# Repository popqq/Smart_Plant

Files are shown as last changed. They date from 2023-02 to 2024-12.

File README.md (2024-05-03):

[][documentation]
[](LICENSE)
[][maintenance]
[][buyit]

# Smart Plant
The Smart Plant is a board that can be plugged directly on the soil, close to the plant, that allows the measurement of the environment (soil moisture, environment temperature & illuminance), and presents the information on an ePaper display.

<p float="left">
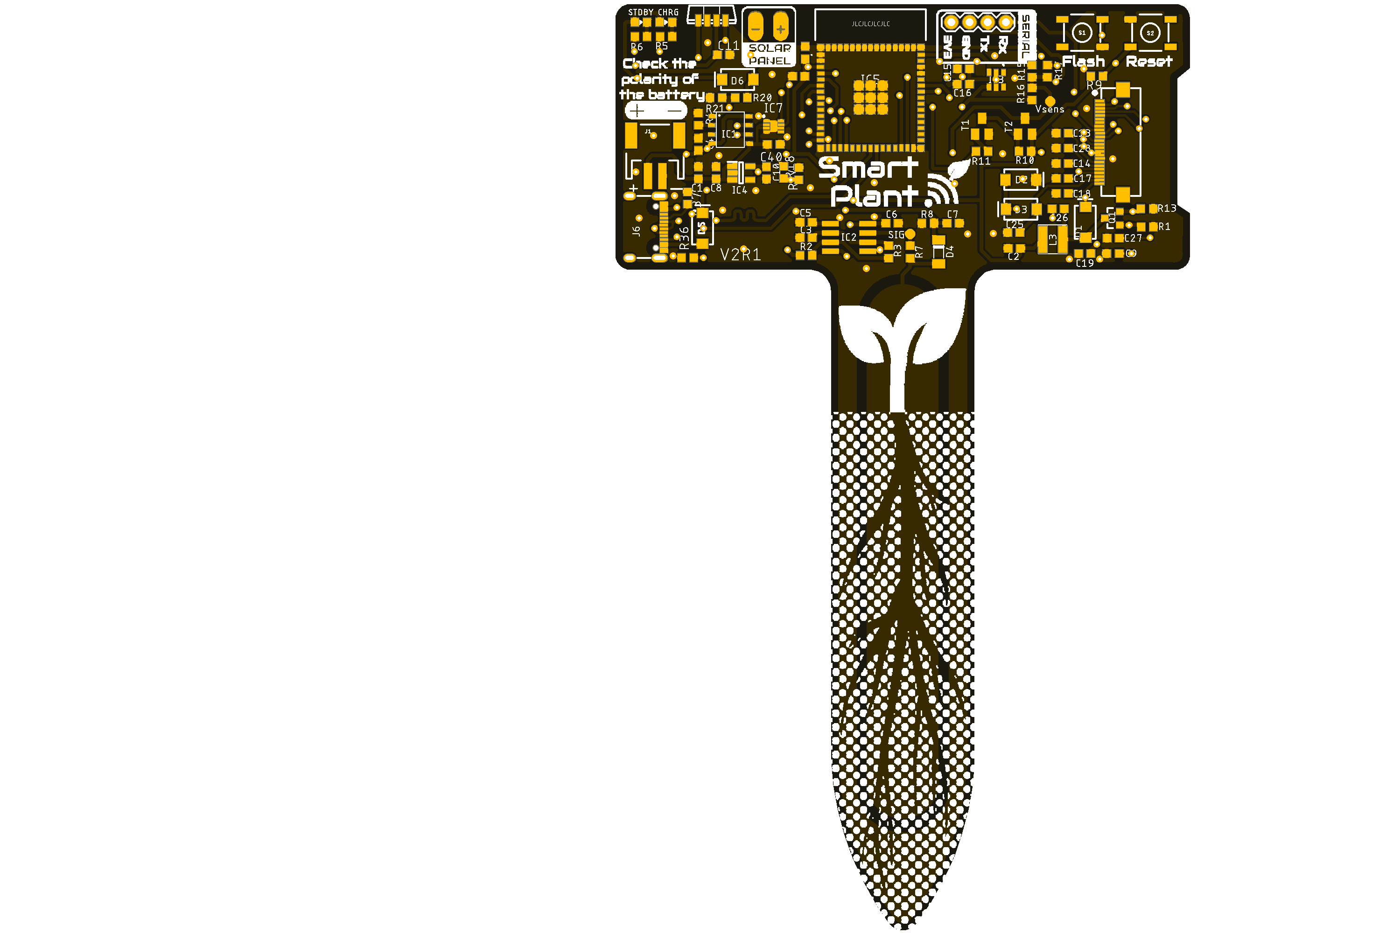
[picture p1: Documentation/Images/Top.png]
   
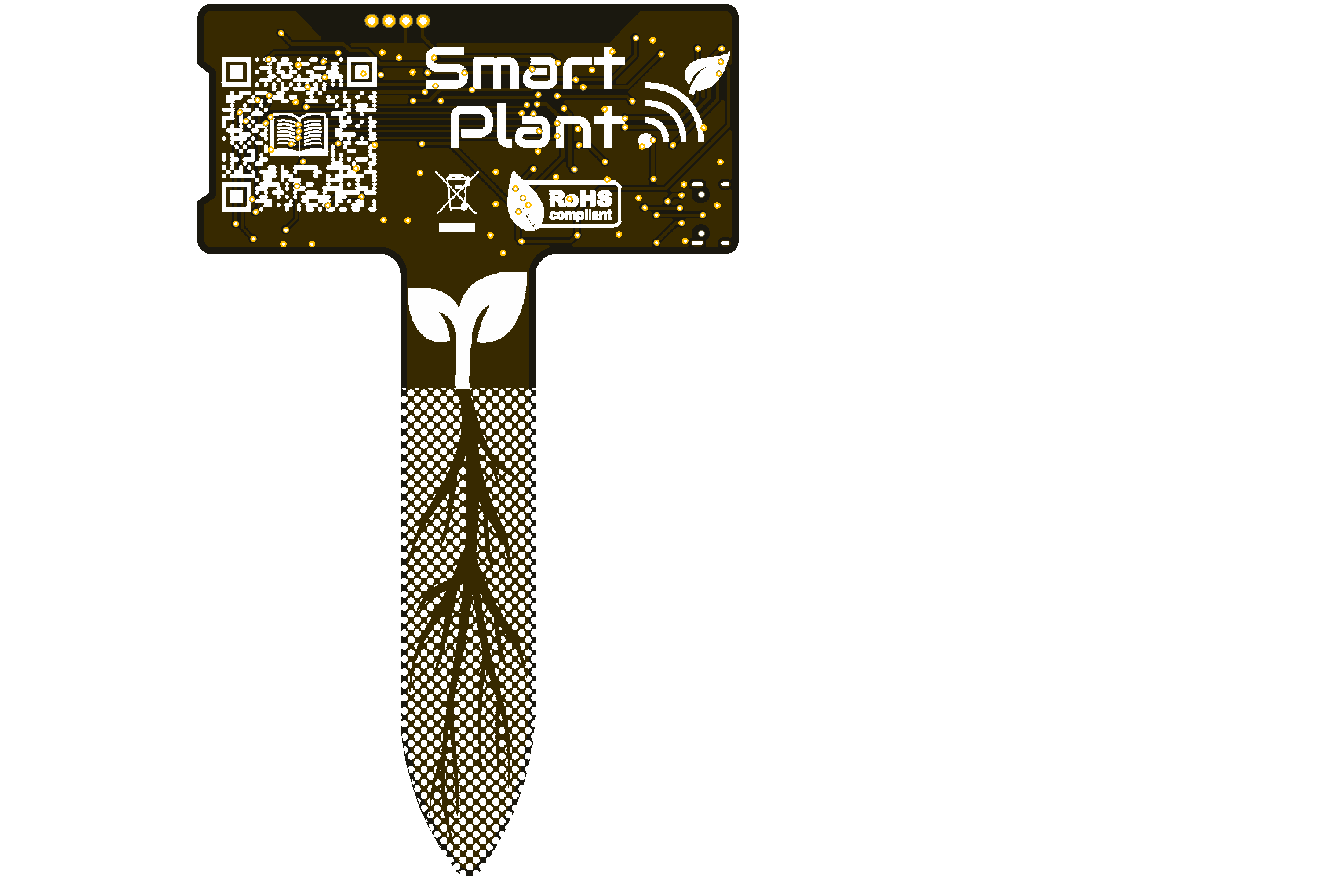
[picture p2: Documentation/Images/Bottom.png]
      
</p>

## Project tree

<li><a href="./Design/">Design</a></li>
<li><a href="./Documentation/">Documentation</a></li>

<li><a href="./README.md">README.md</a></li>

[documentation-shield]: https://readthedocs.org/projects/smart-plant/badge/?version=v2r1&style=for-the-badge
[documentation]: https://smart-plant.readthedocs.io/

[license-shield]: https://img.shields.io/badge/License-CC%20BY--NC--SA%204.0-lightgrey.svg?style=for-the-badge

[maintenance-shield]: https://img.shields.io/badge/maintainer-J.%20G.%20Aguado-2e48a7.svg?style=for-the-badge
[maintenance]: https://github.com/JGAguado

[buyit-shield]: https://img.shields.io/badge/get%20it%20on-elecrow-399BD7.svg?style=for-the-badge
[buyit]: https://www.elecrow.com/smart-plant.html

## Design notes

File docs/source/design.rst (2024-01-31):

📐 Design
===========================

Electronic schematics
---------------------
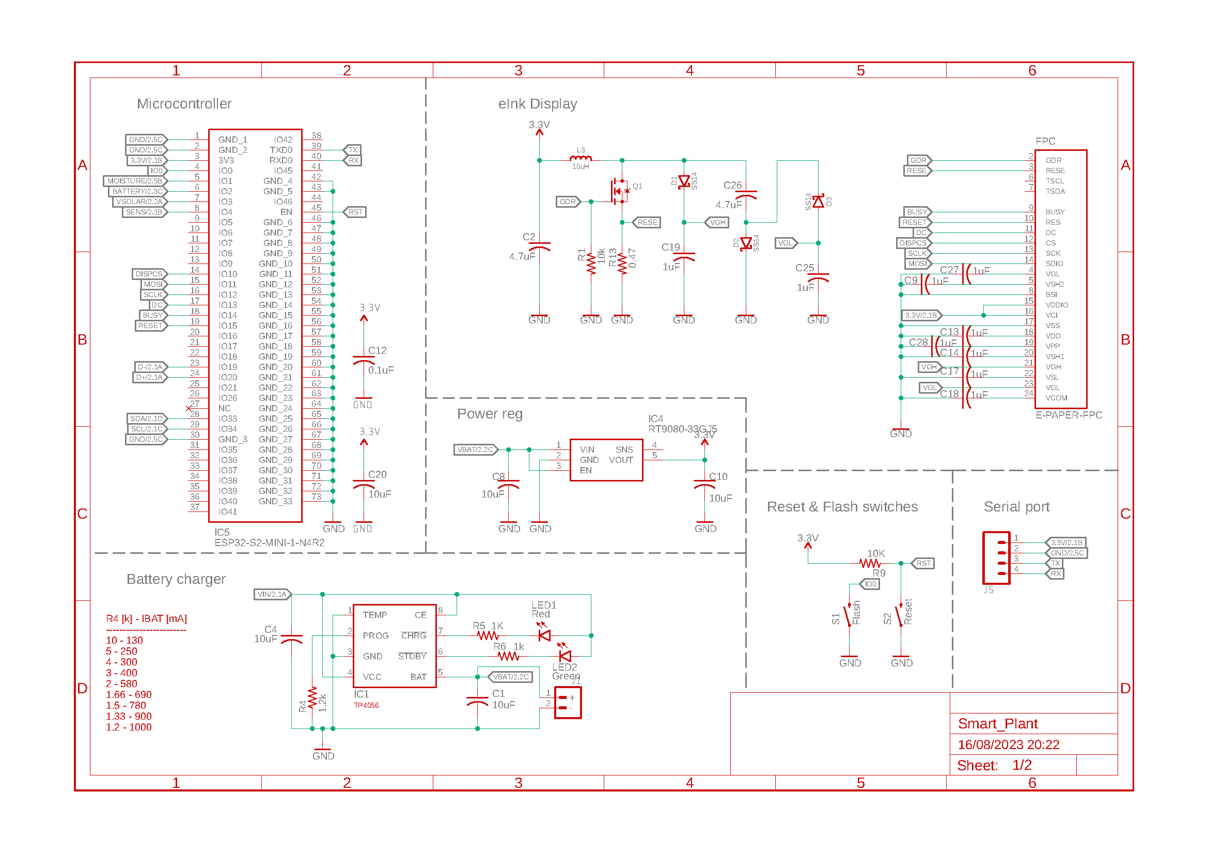
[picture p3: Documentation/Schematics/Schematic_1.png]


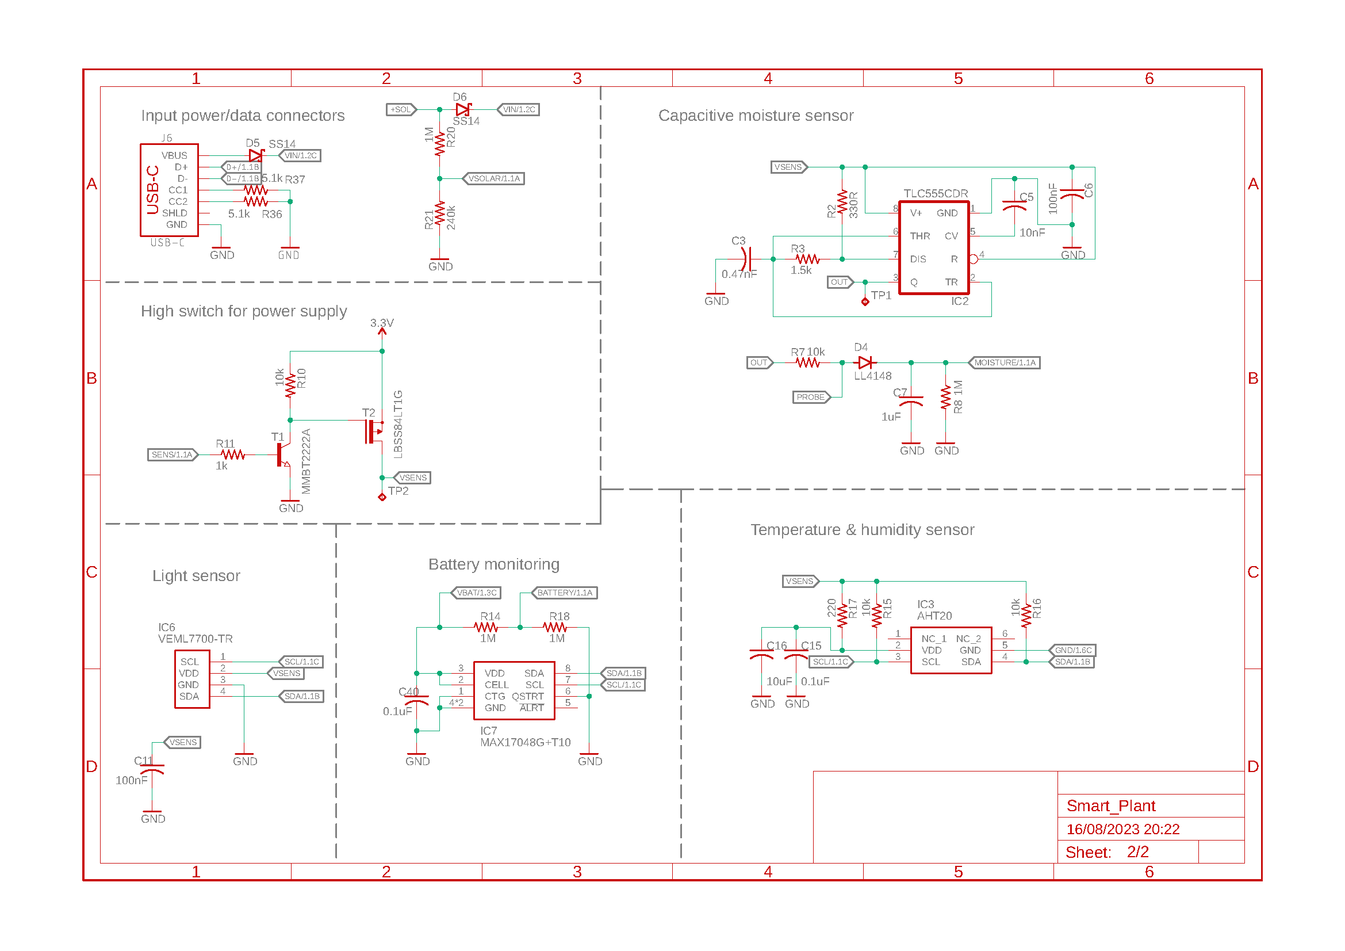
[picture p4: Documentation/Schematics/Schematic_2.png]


:download:`Download PDF <../../Documentation/Schematics/Schematic.pdf>`

.. _pcb:

:term:`PCB`
----------

.. raw:: html

    <iframe src="_static/ibom.html" height="800px" width="100%"></iframe>

.. _enclosure:

3D printable enclosure
-----------------------

FDM version
^^^^^^^^^^^^^^^^^
This 3D model is intended to be printed on :term:`FDM` printers. Check your printing configuration for obtaining the best results on ~2mm thick walls.

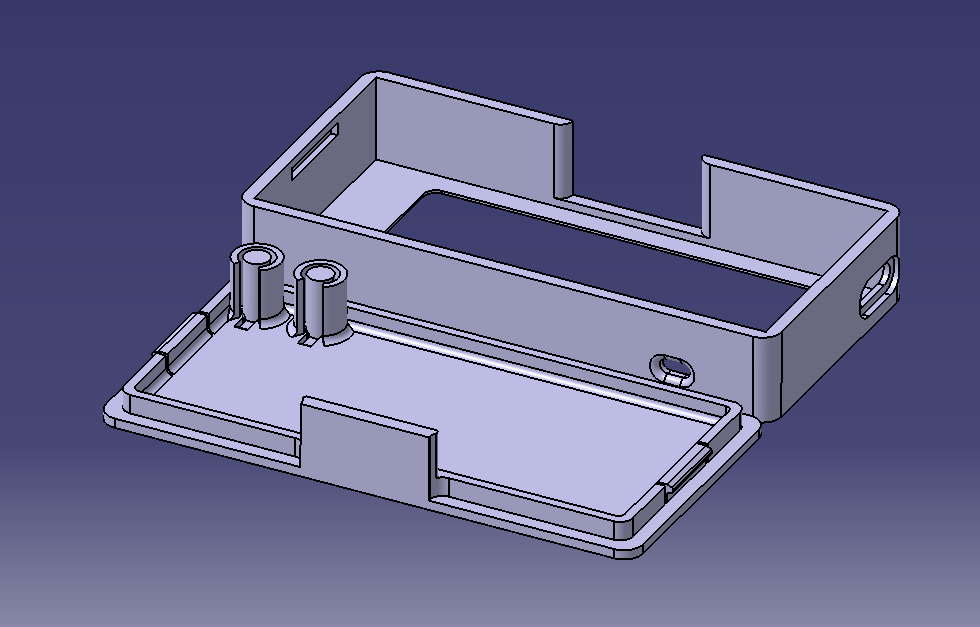
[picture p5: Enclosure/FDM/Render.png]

    
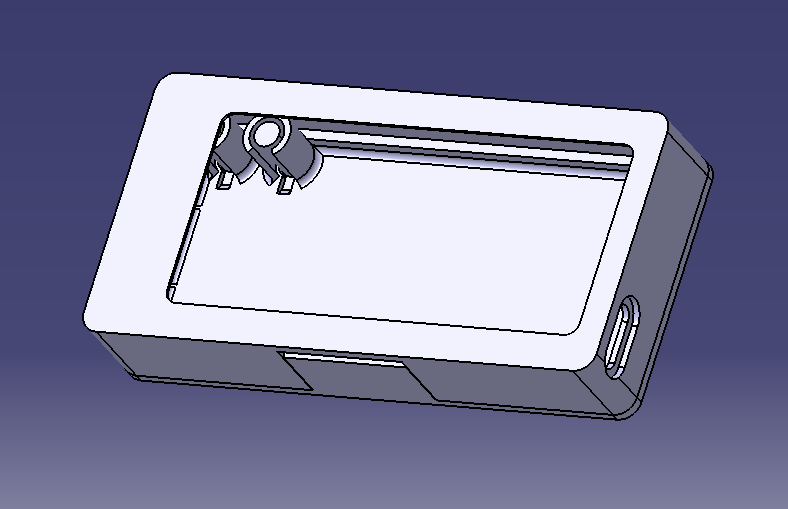
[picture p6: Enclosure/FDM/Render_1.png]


|

Printable STL files:

- :download:`Bottom STL<../../Enclosure/FDM/Smart-Plant Enclosure Bottom.stl>`
- :download:`Top STL<../../Enclosure/FDM/Smart-Plant Enclosure Top.stl>`

Editable STEP files:

- :download:`Bottom STP<../../Enclosure/FDM/Smart-Plant Enclosure Bottom.stp>`
- :download:`Top STP<../../Enclosure/FDM/Smart-Plant Enclosure Top.stp>`

SLA version
^^^^^^^^^^^^^^^^^
This 3D model is intended to be printed on :term:`SLA` printers. 
If you want to use transparent resins, you can download the *Top transparent* version, without holes for the sensor or the display.


    


|

Printable STL files:

- :download:`Bottom STL<../../Enclosure/SLA/Smart-Plant Enclosure Bottom.stl>`
- :download:`Top STL<../../Enclosure/SLA/Smart-Plant Enclosure Top.stl>`
- :download:`Top transparent STL<../../Enclosure/SLA/Smart-Plant Enclosure Top - Transparent.stl>`

Editable STEP files:

- :download:`Bottom STP<../../Enclosure/SLA/Smart-Plant Enclosure Bottom.stp>`
- :download:`Top STP<../../Enclosure/SLA/Smart-Plant Enclosure Top.stp>`
- :download:`Top transparent STP<../../Enclosure/SLA/Smart-Plant Enclosure Top - Transparent.stp>`

Community's versions
^^^^^^^^^^^^^^^^^^^^^^

- `@Paulomart <https://github.com/Paulomart>`_ created a more streamlined button operation version for the bottom part. Check it out on `Printables <https://www.printables.com/de/model/745390-smart-plant-bottom-enclosure-with-improved-buttons>`_.



Technical Specifications
-------------------------

Microcontroller 
^^^^^^^^^^^^
.. list-table:: 
    :widths: 50 80
    :stub-columns: 1

    * - Module
      - ESP32-S2-MINI-1
    * - SoC
      - Xtensa® singlecore 32-bit LX7 up to 240MHz
    * - Flash
      - 4MB
    * - PSRAM
      - 2MB

Power
^^^^^^^^^^^^

.. list-table:: 
    :widths: 50 80
    :stub-columns: 1

    * - Battery 
      - LiPo 3.7 V 1000 mAh
    * - Input (USB/Solar panel)
      - 5V @ 500mA

Features
^^^^^^^^^^^^

.. list-table:: 
    :widths: 50 80
    :stub-columns: 1

    * - Interface 
      - USB Type C 
    * - 
      - 2.4GHz WiFi 
    * - 
      - UART
    * - Display
      - 2.9" e-paper 
    * - Sensors
      - Capacitive soil moisture probe (analog)
    * - 
      - VEML7700-TR illuminance sensor (digital :math:`I^2C`)
    * - 
      - AHT20 air temperature & relative humidity sensor (digital :math:`I^2C`)
    * - 
      - MAX17048 battery voltage level sensor (digital :math:`I^2C`)

Dimensions
^^^^^^^^^^^^

.. list-table:: 
    :widths: 50 80
    :stub-columns: 1

    * - Size 
      - 130x80x7mm
    * - 
      - 132x84x15mm with enclosure
    * - Weight
      - 20g
    * - 
      - 45g with battery

Environment
^^^^^^^^^^^^
.. Caution::
    If the |Product| is placed on the soil close to the plant, be careful at the moment of wattering your plant: avoid splashes 
    or flooding the pot.

.. list-table:: 
    :widths: 50 20 20 20 20 20
    :header-rows: 1
    :stub-columns: 1

    * - Parameter
      - Symbol
      - Min.
      - Typ.
      - Max.
      - Unit
    * - Working temperature [1]_
      - :math:`T_{amb}`
      - 0
      - 25 
      - 60
      - *°C*
    * - Storage temperature [1]_
      - :math:`T_{amb}`
      - 0
      - 25 
      - 60
      - *°C*

.. [1] Based on components datasheets.

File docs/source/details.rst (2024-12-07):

💡 Details
===============

.. _pinout:

Pinout
---------
The |Product| integrates an ESP32-S2 microcontroller with the following pinout:

.. list-table:: Pinout table
    :widths: 10 10 40
    :header-rows: 1

    * - **Component**
      - **Pin**
      - **Description**
    * - **I²C**
      - 
      - 
    * - Serial Clock Line (SCL)
      - GPIO34
      - Used for I²C communication clock signal
    * - Serial Data Line (SDA)
      - GPIO33
      - Used for I²C communication data signal
    * - **SPI**
      - 
      - 
    * - Clock (CLK)
      - GPIO12
      - SPI clock signal
    * - Master Out Slave In (MOSI)
      - GPIO11
      - SPI data from master to slave
    * - **Analog/Digital Sensors**
      - 
      - 
    * - Battery Voltage (ADC)
      - GPIO2
      - Reads battery voltage level
    * - Solar Input (ADC)
      - GPIO3
      - Reads voltage from the solar input pad
    * - Soil Moisture (ADC)
      - GPIO1
      - Measures soil moisture
    * - **Digital Outputs**
      - 
      - 
    * - Excitation Switch
      - GPIO4
      - Controls excitation signal for powering the sensors
    * - **Display (WaveShare E-Paper)**
      - 
      - 
    * - Chip Select (CS)
      - GPIO10
      - Selects the e-paper display module
    * - Data/Command (DC)
      - GPIO13
      - Differentiates between data and commands
    * - Busy Indicator (BUSY)
      - GPIO14
      - Signals when the display is busy
    * - Reset (RST)
      - GPIO15
      - Resets the display module

Power
--------
The |Product| is be powered through a :term:`LiPo` battery plugged into the white JST connector. The voltage of the battery is regulated to the working 3.3V through a low-consumption :term:`LDO`.

.. Caution::
    Connect the battery after clamping the e-paper connector and be careful when plugging it or removing it, since the connector can be hard to plug/unplug.

In order to charge the battery, there is a battery management IC that provides the right charging curve to the :term:`LiPo` battery and offers a visual indicator (red LED for charging, 
green LED for standby) while the battery is being charged. There are two ways of charging the |Product|: USB-C or solar panel.

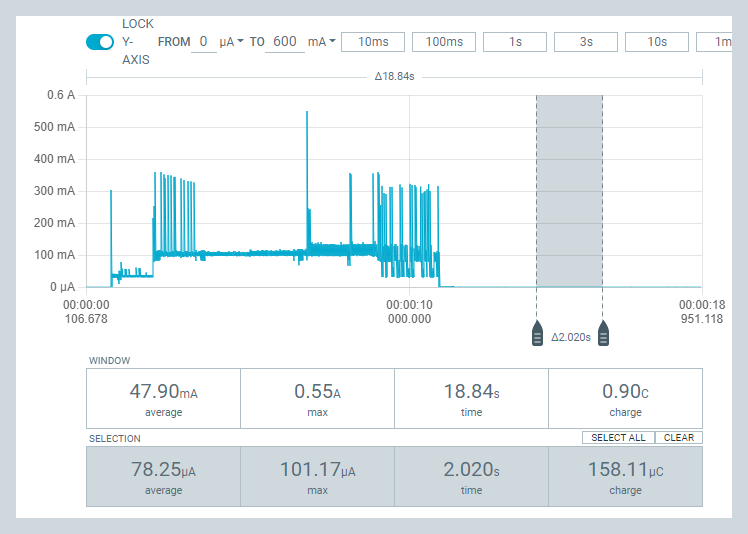
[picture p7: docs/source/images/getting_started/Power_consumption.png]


Solar panel
^^^^^^^^^^^^^
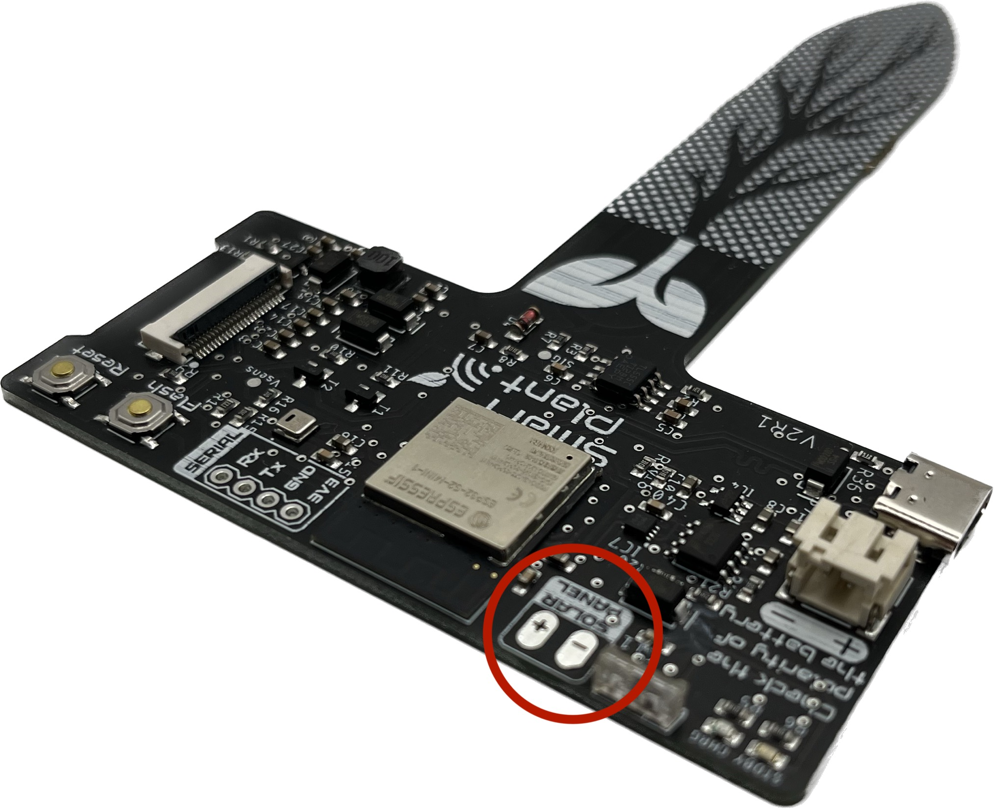
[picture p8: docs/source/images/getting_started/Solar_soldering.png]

    
In addition to the USB-C, and with the aim of extending the service time between (USB) charges of the battery, the |Product| can be configured to be powered from a solar panel. This feature 
would imply soldering the solar pannel to the board as indicated in the figure.

USB-C
^^^^^^^^^^^^^
The USB Type-C is a very extended port for portable electronics, and because of it's standarized 5V power supply is ideal for charging the |Product|.

Sensors
--------   
As the |Product| is intended to work during long periods of time without having to be recharged, it is important to avoid undesired consumptions 
durint the deep-sleep periods. This implies that the sensors have to be powered **only** when they are needed. 

Therefore there is a high-switch circuit that enables/disables the powering of the *sensors power line* connected to the microcontroller's output **GPIO4**.

Regarding the sensors, and except for the soil moisture sensor which is analog, the rest (illuminance, temperature & humidity, battery status) are :term:`IIC` (:math:`I^2C`) sensors,
which are physically defined with the following pinout:

:SDA: **GPIO33**
:SCL: **GPIO34**

Soil moisture
^^^^^^^^^^^^^^
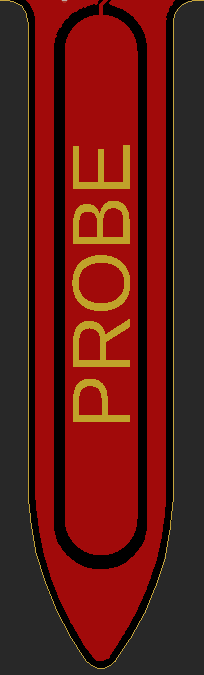
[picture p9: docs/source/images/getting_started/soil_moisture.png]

    
Since the |Product| can be directly inserted into the soil of your pot, the area inserted contains a printed circuit that behaves as a 
probe that measures the soil capacity, determined by the soil moisture. As it has no metallic electrodes, there is no risk of probe degradation 
with time. 

The moisture level, in a 0-3.3V range, is measured through the ADC on **GPIO1**

|
|

Light sensor
^^^^^^^^^^^^^^^^^^^^^^^
The illuminance is measured through a digital sensor VEML7700-TR. This sensor is located facing the outside of the top part of the board, so it 
would be facing the sky. 

The VEML7700 is quite a convenient sensor since it delivers the values directly in lux. 
The sensor has 16-bit dynamic range for ambient light detection from 0 lux to about 120k lux with resolution down to 0.0036 lx/ct, 
with software-adjustable gain and integration times.

The :math:`I^2C` address is **0x10**.

.. Hint::
    If you are designing your own enclosure, make sure there is a hole for the light sensor on the case.

Ambient temperature & humidity 
^^^^^^^^^^^^^^^^^^^^^^^^^^^^^^^
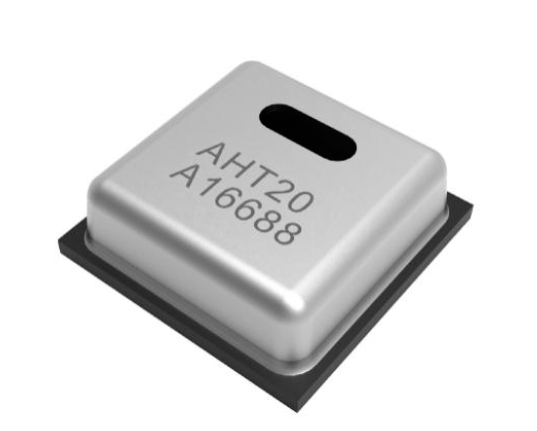
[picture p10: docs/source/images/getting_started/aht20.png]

The |Product| embeds an AHT20 temperature and humidity sensor ready to deliver calibrated data through the :math:`I^2C` bus.

This sensor has an operational relative humidity range of 0 to 100% ( with a ±3 % typical accuracy), and a temperature range of -40 to 85 °C (±1 °C typical accuracy)

The :math:`I^2C` address is **0x38**.

Battery level
^^^^^^^^^^^^^^^^
For measuring the battery level, the |Product| integrates the MAX17048 :term:`IC`.

This sensor measures the voltage of the LiPo cell and does the math to get an estimative percentage of the battery level.

The :math:`I^2C` address is **0x36**.

E-paper
--------
    
The e-ink display pinout with respect to the ESP32 GPIOs goes as follows:

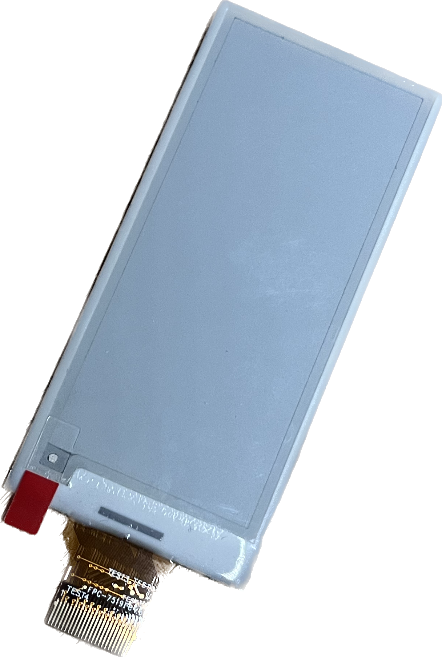
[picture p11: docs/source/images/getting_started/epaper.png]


.. list-table:: Pinout table
    :widths: 10 10 
    :header-rows: 1

    * - ESP32
      - E-paper
    * - 14
      - BUSY
    * - 15
      - RST
    * - 13
      - DC/MISO
    * - 12
      - CLK
    * - 11
      - MOSI
    * - 10
      - CS

Enclosure
---------
The |Product| PCB can be mounted in a custom :ref:`enclosure` that you can print on your own 3D printer.

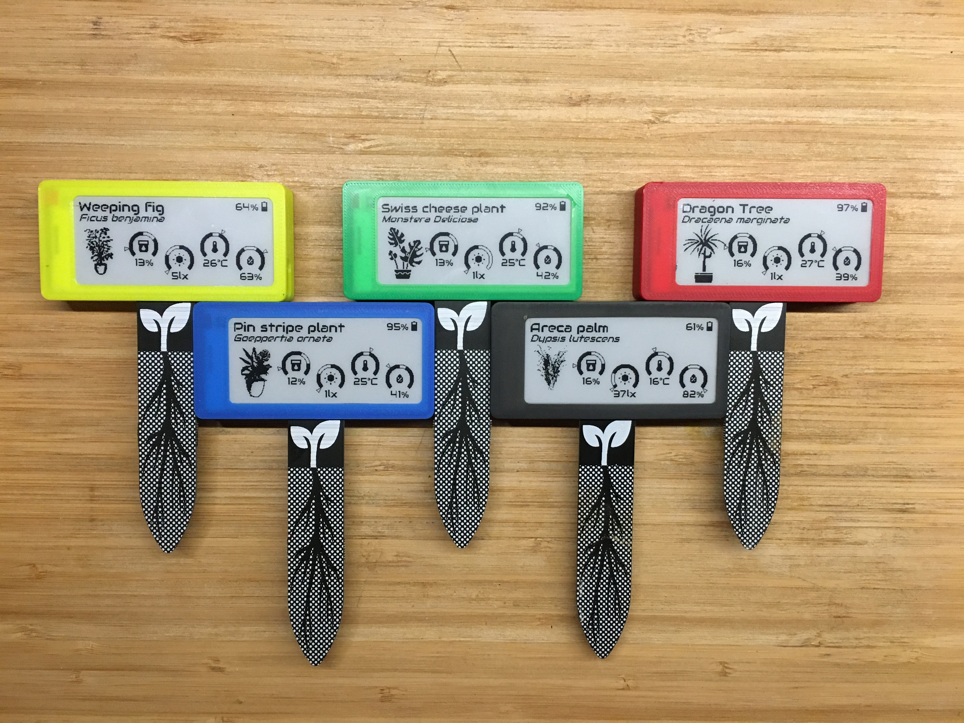
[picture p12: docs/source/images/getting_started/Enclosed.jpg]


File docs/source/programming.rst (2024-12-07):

💻 Programming
===============

There are two main programming methods supported and tested with the |Product|: 

 * ESPHome
 * Arduino

.. _flashing:
In both scenarios, and if you are using the USB port or the Serial port for programming it, you
will first need to enter the board into flashing mode: press and hold the *Flash* pushbutton
while you reset the board (pressing once the *Reset* pushbutton).

.. Caution::
    When flashing the board, make sure its only powered by the USB/Serial port.
ESPHome
---------
`ESPHome <https://esphome.io>`_ is a well known platform for programming ESP-based devices 
with a very little effort. It is configured via YAML files and supports a wide range of functionalities
and sensors.

.. Hint::
    For using ESPHome, and all its funcionalities, you need to have a `Home Assistant <https://www.home-assistant.io>`_ instance running
    in the same network as your |Product|.

The |Product| comes raw, without any firmware by default, therefore, you will need to flash it for first time. There are many ways to flash 
your ESPHome device (`locally <https://esphome.io/guides/getting_started_command_line.html>`_, `ESPHome Web <https://web.esphome.io>`_), but 
the one I strongly recommend is the one through the `ESPHome Add-on for Home Assistant <https://esphome.io/guides/getting_started_hassio.html>`_:

.. Error::
    For the last months, the `ESPHome Web <https://web.esphome.io>`_ web has been having some issues when trying to flash ESP32-S2 modules. Therefore the best way to flash it for first time is with the ESPHome HA (Home Assistant) add-on running on a Raspberry Pi and the Smart Powermeter connected to the RPi.

1. Make sure your ESPHome Add-on for HA is up to date and working. 
2. Add a new device, enter the name you want (like *Smart-Plant*), and skip the next step.
3. Select the *ESP32-S2* as the device type, skip the last step (installation). You will have created a provisional first configuration YAML file.

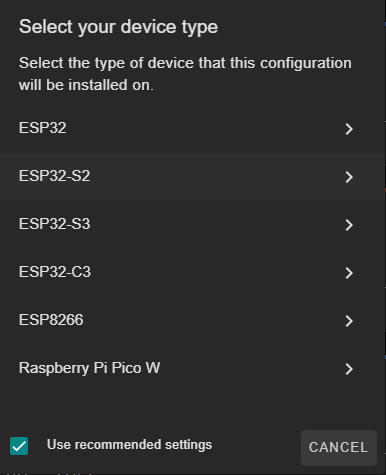
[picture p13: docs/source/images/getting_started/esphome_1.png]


4. Open the recently created file and replace the content with the example configuration ``smart-plant.yaml``

.. Note:: You might need to keep the encription keys *OTA* and *API*

.. literalinclude:: files/configuration.yaml
   :language: yaml
   :linenos:

.. Important:: 
    Note that with this example code, the Smart Plant enters into deep-sleep mode if the battery level is under a 95% (lines 393-401), so be aware that if you want to flash it :term:`OTA`, make sure the battery is fully charged or the Smart Plant powered via USB-C.

.. Note::
    The Smart Plant integrates a *battery gauge* sensor (MAX17048), not natively supported by ESPHome at the moment. However by adding the following code, it would work::

        external_components:
            - source: github://Option-Zero/esphome-components@max17048
                components: [max17048]
        sensor:
            - platform: max17048
              battery_voltage:
                name: Battery voltage
              battery_level:
                name: Battery level
              rate:
                name: Battery discharge rate

.. Note::
    ``Lemon_tree_label_page_1.png`` is the background image that will be displayed on the e-paper. For having always a styled background image, I made a `python script <https://github.com/JGAguado/Label-maker>`_ that generates the image of the plant, the title and the parameter 
    gauges out of a JSON config file. Alternativelly, you can use any photo editor of your choice, but keep in mind the display size 
    (296x128 pixel) and the center of each gauges (indicated in the YAML code). In this example, it is obtained from an URL, but you can upload yours locally following the `ESPHome guide <https://esphome.io/components/display/index.html#images>`_

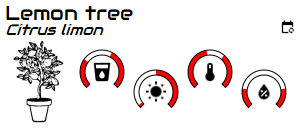
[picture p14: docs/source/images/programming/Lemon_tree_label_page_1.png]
    

5. Click on install, make sure that the the board is connected via the USB-C (and into `flashing`_ mode ) to the device running the Home Assistant (in my case a Raspberry Pi) before selecting the mode of installation.

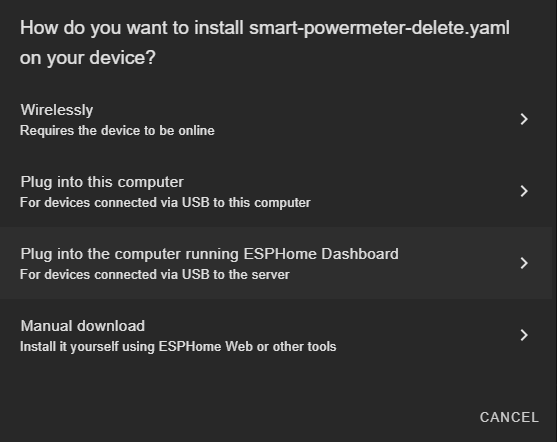
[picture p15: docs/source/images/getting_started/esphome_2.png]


6. Select the Serial port and let it run, it might take some minutes. 
7. Once it's done, you will have to exit the flashing mode: press the *Reset* pushbutton once. 

Now, your ESPHome-based |Product| should be ready to log data and stream it to your Home Assistant. Note that the current configuration is just an example and you can customize it at your will, including the calibration. 

.. Tip::
    A very easy way to upload and copy files (code or even images) into your ESPHome folder hosted in your HA instance is 
    with the help of the Visual Studio Code integration for HA. This way you can just drag and drop the files over the folder 
    on the Home Assistant’s Visual Studio Code navigation panel on your left.

Flash Tools
^^^^^^^^^^^^
If you want to deploy an ESPHome already compiled *.bin* image, you can use Espressif's official `Flash Download Tools <https://www.espressif.com/en/support/download/other-tools>`_ to upload it into your Smart Powermeter. 
As an example (and test) you can use this :download:`smart-areca-v2r1-offline.bin <files/smart-areca-v2r1-offline.bin>` image with the address `0x0`, make sure `DoNotChgBin` is checked:

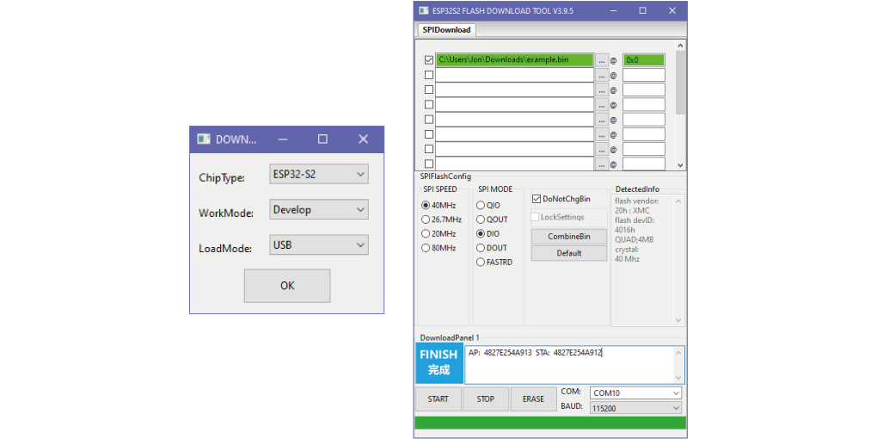
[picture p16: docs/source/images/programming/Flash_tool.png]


Arduino
--------
If you are still interested in programming directly with the Arduino IDE, the procedure is no 
different than with any other ESP32 devices:

1. Open the Arduino IDE and go to File -> Preferences option.
2. Add to the *Additional Boards Manager URSLs* the url:

.. parsed-literal::

    https://raw.githubusercontent.com/espressif/arduino-esp32/gh-pages/package_esp32_index.json

3. Close the preferences and open in the menu Tools -> Board -> Boards Manager.
4. Search for *esp32* and install it. This might take some time.
5. Now you can select the board *ESP32 Dev Module* as the target board. Leave the rest of parameters 
   by default.
6. Select the correct port and remember to enter the board into flashing mode before uploading the sketch.

.. Tip::
    Remember to check out the full :ref:`pinout`

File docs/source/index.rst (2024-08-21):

Smart Plant
###############

.. raw:: html
        
    <iframe src="_static/carousel.html" style="width: 100%; height: 300px; border: none;"></iframe>

Welcome to the documentation page of the |Product|, a device to monitor the environmental conditions of your favourite plant.

With the |Product| you can measure a range of paramaters such as the soil moisture, ambient light and the air temperature & relative humidity. 
In adition to the IoT capabilities of streaming the measured parameters into your favourite platform, like Home Assistant, you can read the data directly on 
the integrated 2.9" e-paper display.

As you can imagine, all this features would be useless if the design is not optimized to consume the lowest energy possible: thanks to the deep-sleep features of 
the ESP32 microcontroller, a selection of low-consumption electronics (high-efficient LDOs in standby modes, power-switched sensors and partially refreshed e-paper) 
and the optional solar cell. 

Everything packed in a quite compact but elegant device that can be directly plugged into your plant's pot.

Contents
--------

:doc:`safety`
    How to operate and manipulate the |Product|.

🛒 `Buy <https://www.elecrow.com/smart-plant.html>`_
    Get your own |Product| kit today.

:doc:`details`
    A deeper explanation on the systems of the |Product|.

:doc:`getting_started`
    First steps for configuring and working with the |Product|.

:doc:`design`
    Design files of the |Product|.

And comming soon ...
--------------------

If you like this project and you would be interested on the future Smart Plant device, developed into a more user-friendly and finished product, leave your contact details and we will come back to you as soon as we have news!

.. raw:: html
        
    <iframe src="_static/newsletter.html" style="width: 100%; height: 400px; border: none;"></iframe>

.. Important::
    You will not receive any confirmation email. However, as soon as we are ready to release some info about the new Smart Plant device, you will be the first one to know!

.. _support:

Technical support
-----------------

If you have technical problems or cannot find the information that you need in the provided documentation, 
please contact me directly:

:Author: |Author|
:Contact: |Email|

:Board: |Product|
:Revision: |Version|
:Date: |Date|

.. toctree::
   :maxdepth: 3
   :hidden:

   safety   
   🛒 Buy <https://www.elecrow.com/smart-plant.html>   
   details
   getting_started
   design   
   glossary
   faq

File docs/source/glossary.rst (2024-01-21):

📚 Acronyms
============

.. glossary:: 
   :sorted:

   IC
       Integrated Circuit

   TTL
       Transistor-Transistor Logic

   I/O
       Inputs / Outputs

   GND
       Ground

   OTA
       Over-the-Air

   PCB
       Printed Circuit Board

   PWM
       Pulse-width Modulation

   FF
       Flip Flop

   FAQ
       Frequently Answered Questions

   FPC
       Flexible Printed Circuit

   LED
       Light Emitting Diode

   LDR
       Light Dependant Resistor

   LDO
       Low-Dropout regulator 

   RGBW
       Red-Green-Blue-White

   NTC
       Negative Temperature Coefficient

   MDI
       Material Design Icons

   BOM
       Bill of Materials

   ESD
       Electrostatic Discharge

   SMD
       Surface-mounted device

   SMT
       Surface-mount Technology

   THT
       Through Hole Technology

   IIC
       Inter-Integrated Circuit

   FDM
       Fused deposition modeling

   SLA
       Stereolithography

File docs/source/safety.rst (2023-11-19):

🦺 Safety guidelines
=================

These safety guidelines, the operation instructions and the limit values listed in :doc:`specs` are to be read carefully before operating the product.

.. Caution::
    This product has been designed for being used in domotic applications. 
    It was not designed for any use involving serious risks or hazards that could lead to death, injury, serious physical damage, or loss of any kind without the implementation of exceptionally stringent safety precautions.

:term:`LiPo` battery powered
----------------------
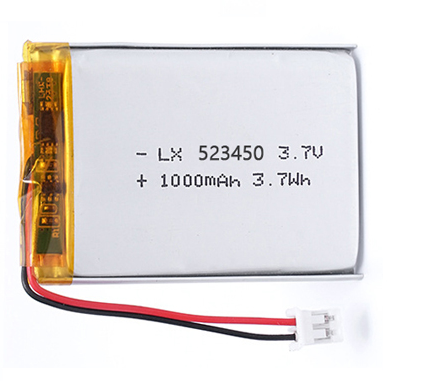
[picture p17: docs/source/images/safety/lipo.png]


Due to the high power density of :term:`LiPo` batteries, the |Product| is powered directly by a 1000mAh :term:`LiPo` battery. Therefore there are specific electronics embeded in charge of the battery 
management, including charge/discharge of the battery and protections against low-voltage levels and short-circuits. 

However it's not recommended to leave the product unatended while charging for long time through the C-Type USB. In case you observe a high increase of the device's temperature or you 
smell burn, immediatelly disconnect the device from the charging USB.

In case you are using the optional solar panel for extending the autonomy and you feel the device gets too hot from the solar charging, please cover the solar panel until you see 
the charging LED goes off.

If you have any question, please check with technical support (:ref:`support`) before taking any action potentially dangerous.

Protection against :term:`ESD`
------------------------------

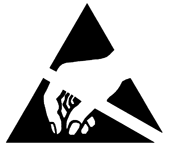
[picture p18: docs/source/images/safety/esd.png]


The |Product| contains components sensitive to :term:`ESD`, which can be damaged by inappropriate handling. 
It's therefore necessary to provide some safety precautions against :term:`ESD` during the handling and operation.

Usage, transport and storage
----------------------------

During the use, transport and storage, this product must be protected from any mechanical stress 
(forces applied over the board or it's components), temperatures out of the data-sheet's range, high 
environmental humidity or aggressive atmospheres.

Avoid using it in areas where it cannot be assured the previously mentioned environmental conditions.

Repairs
-------

If any of the components on the board gets damaged, a reparation is possible. This repair can be performed by 
yourself if you identify the problem and have the means for desoldering & soldering. If this is not the case,
just write to the :ref:`support` mail to reach a solution.

Disposal
--------

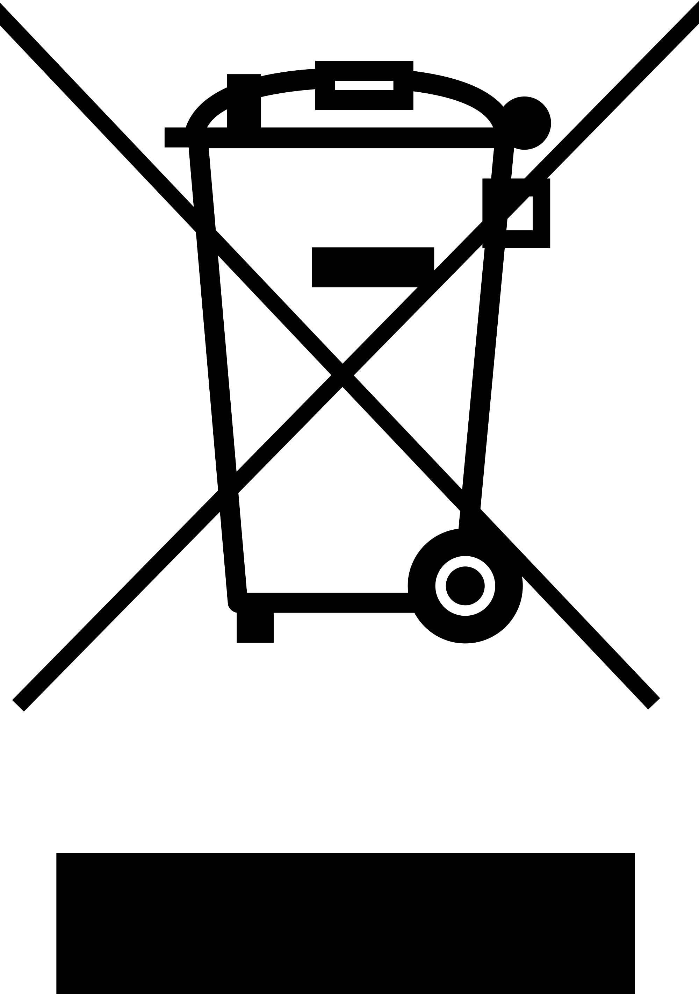
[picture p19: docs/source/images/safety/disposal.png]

    
In accordance with national and local environmental protection and material recovery and recycling regulations, 
electronic devices that can no longer be used (in case a repair is not possible) must be disposed of separately 
and not with normal household garbage.

Restriction of Hazardous Substances
-----------------------------------

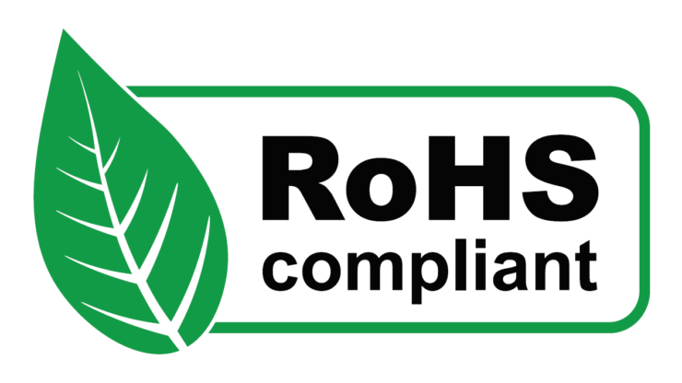
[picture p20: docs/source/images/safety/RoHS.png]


The :term:`PCB` and the electronic components mounted on the |Product| have been manufactured attending to the EU rules 
restricting the use of hazardous substances (RoHS) in electrical and electronic equipment to protect the 
environment and public health.

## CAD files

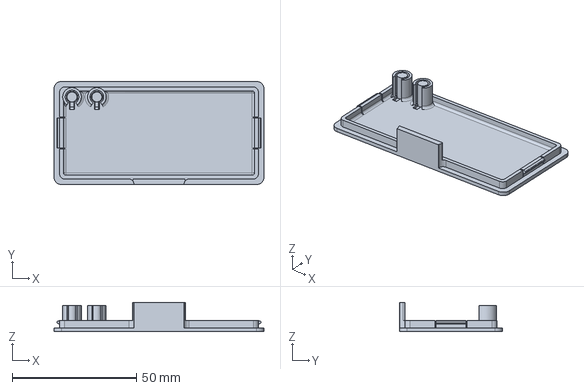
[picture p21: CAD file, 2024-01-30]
Enclosure/FDM/Smart-Plant Enclosure Bottom.stp
84.5 x 41.5 x 11.8 mm

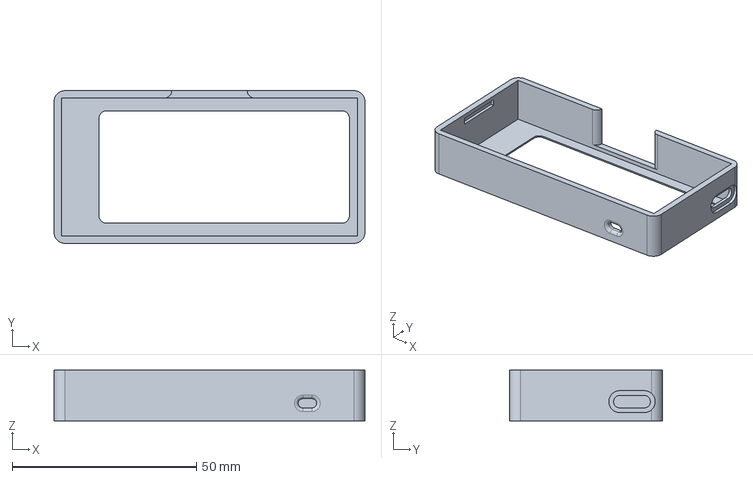
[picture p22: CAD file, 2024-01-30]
Enclosure/SLA/Smart-Plant Enclosure Top.stp
84.5 x 41.5 x 13.8 mm

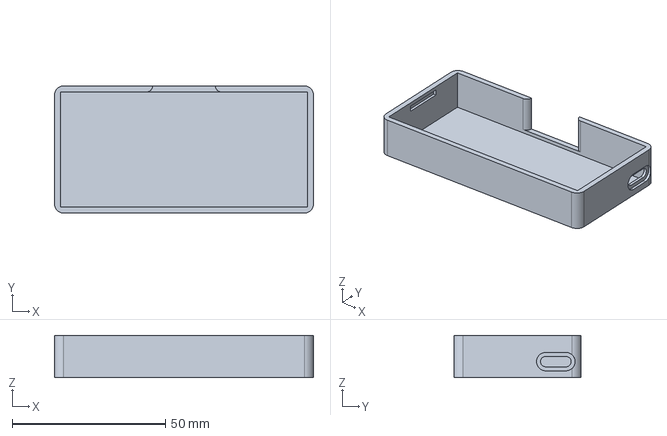
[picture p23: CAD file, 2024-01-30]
Enclosure/SLA/Smart-Plant Enclosure Top - Transparent.stp
84.5 x 41.5 x 13.8 mm

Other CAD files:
Enclosure/FDM/Smart-Plant Enclosure Top.stp
Enclosure/SLA/Smart-Plant Enclosure Bottom.stp
Enclosure/FDM/Smart-Plant Enclosure Bottom.stl
Enclosure/FDM/Smart-Plant Enclosure Top.stl
Enclosure/SLA/Smart-Plant Enclosure Bottom.stl
Enclosure/SLA/Smart-Plant Enclosure Top - Transparent.stl
Enclosure/SLA/Smart-Plant Enclosure Top.stl

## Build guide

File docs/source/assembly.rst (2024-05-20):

🏗️ Assembly
============================

Due to the high amount of components integrated in such small PCB layout, most of them are too small to be soldered at home by you. Therefore, these boards come already 
with the components assembled. 

The |Product|, in addition to the PCB assembled board, consist on the following parts:

- A 2.9" e-paper display. The recommended (and tested working) e-ink panel is the `296x128, 2.9inch E-Ink raw display panel <https://www.waveshare.com/product/2.9inch-e-paper.htm>`_ that you can order directly on the manufacturer. 
  Please note that **other displays may not work at all**.
- A :term:`LiPo` battery, with a recommended 1000mAh capacity, for space and power. The ideal dimensions shouldn't excess the 50x34x5mm in order to fit in the designed enclosure.
- An enclosure where to fit the |Product| upper part that you can find on the :ref:`enclosure` section.
- Optionally, you can mount a solar panel that charges the battery under the right sunny conditions. The output voltage of the panel musn't excess the 6V and the recommended size to fit in the designed enclosure is 80x45mm

In order to assemble your |Product|:

1. Open the clamp connector, by smoothly pulling up the tab.
2. Introduce the e-paper :term:`FPC` with the exposed pads facing up (so that you could still see them)

.. Note::
  The ribbon cable for the e-ink display does not need to be forced in, or slide all the way in. It only goes in a few millimetres, and then the clamp holds it in place.

3. Close the clamp connector

.. Caution::
  Once it's plugged into the |Product|, and without an enclosure, be careful about the e-paper, the connector is fragile and could get damaged if isn't handled with care. It could be useful to use double.sided tape to stuck the screen onto the PCB, just to keep it from flapping loose, but keep in mind that removing it afterwards can damage the e-paper display.

4. Bend carefully the e-paper's :term:`FPC` in a way that the panel rests over the reverse side of the :term:`PCB`.
5. Connect the :term:`LiPo` battery, making sure that the polarity is well respected: red wire is + (positive terminal) and black wire is the - (negative terminal).

At  this point, and without any previous programming, it is normal that the board won't turn on any :term:`LED` or refresh the e-paper; you will need to program it!

Last but not least, make sure you have a fitting enclosure close to you, so you can protect your |Product|. If your printed on of my designs, introduce
the |Product| from the e-paper side connector first before finishing entering the USB-C side.

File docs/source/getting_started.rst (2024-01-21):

🚀 Getting started
===============
  
    Trust me, I know what I'm doing...

    -- Every engineer while ignoring the instructions book.

Regardless of your professional background, I encourage you to have a quick read through the following pages in order to get your |Product| 
onboarding smoother and minimize the risk of damaging the device and/or yourself.

.. toctree::
   :maxdepth: 2

   assembly
   programming

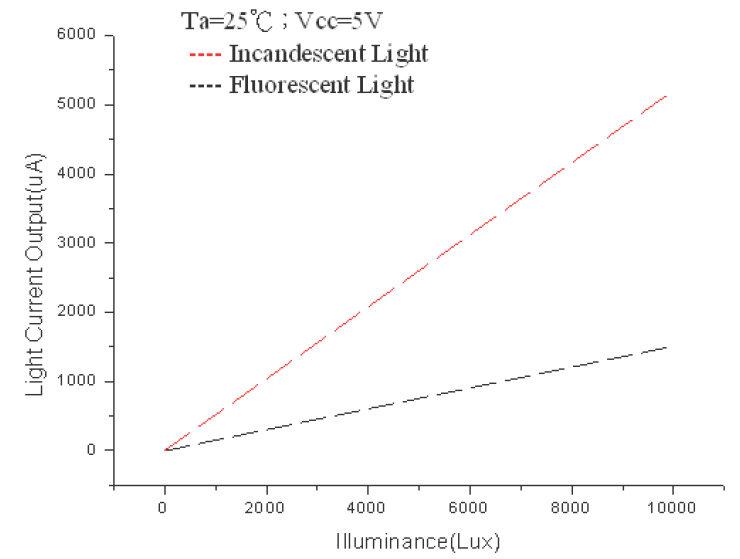
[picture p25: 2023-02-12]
docs/source/images/getting_started/Illuminance.png

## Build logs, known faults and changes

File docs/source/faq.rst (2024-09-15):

💬 :term:`FAQ`
=============================

When trying to flash the |Product| with `ESPHome Web <https://web.esphome.io>`_ , I get a spinning ring with "connecting" for a few seconds and then it errors out with "Failed to initialize".
    This is an issue related to `ESPHome Web <https://web.esphome.io>`_ when trying to flash ESP32-S2 modules and (at the moment of writing this guide) is still unsolved. Please check alternative ways (on the :ref:`esphome` programming section) of flashing the |Product|. 

After connecting the battery, I don't see the e-paper refresh or any LED on.
    The two LEDs that are on the board (STDBY & CHRG) only indicate the state of the battery while charging (USB-C or solar panel). The way to 
    check if the SmartPlant is alive is pressing the Reset pushbutton and see that the e-paper refreshes correctly. If not, you will need to 
    charge the battery through the USB-C. 

After connecting the battery and the USB power I see the both LED (STDBY & CHRG) on.
    Check the battery connection polarity: red with + and black/blue with -. 
    Since there is no standard relative to the JST connectors polarity, please pay 
    special attention when connecting any battery to the board. 

Can I upload ESPHome directly from the Home Assistance setup running on my Raspberry Pi?
    Yes you can, and actually this is one of the simplest and more effective way to upload ESPHome.

Can I upload firmware through the USB-C?
    Yes, the ESP32-S2 includes a full-speed USB On-The-Go (OTG) interface to enable USB communication.

When I try to compile the given YAML and upload it into the board I get some error messages saying that I miss some files (Audiowide.ttf, icon-map.h, etc). How to fix it?
    Just the configuration YAML file isn’t enough and you might get an error asking for missing items (the fonts and the images). The reason is because
    on the configuration we are asking for some files (the fonts that you want for the digits or the icons and the background image with the plant and the gauges).
    
    Therefore you need to upload into the folder with the configuration YAML file the required files. I strongly suggest to use Visual studio code and just drag and 
    drop the items according to the structure mentioned on the :ref:`esphome` programming section.

How is the time handled in the board? 
    The time is handled by the ESP32 internal RTC to keep the design compact and straightforward. Therefore the deep-sleep timing is not very 
    precise, I have observed a loss of around 1-2 minutes out of every hour, resulting in a deep sleep period that lasts around 58 minutes 
    instead of 60. However, for the kind of application this is not a quite big issue. 

Can I use it if there is no internet connection? 
    Yes, and based on tests I made, actually will improve the battery duration in almost one week. You just need to adjust the config YAML file 
    and remove the Wifi components.

Can Smart Plant be used outdoor in garden? Is it weatherproof? And with the printed enclosure? 
    I strongly recommend you to avoid placing them outdoor in garden, directly under a water hose/ sprinkles zone
    or heavy rain. Instead use them on indoor plant pots (or a covered balcony). 
    Despite I designed a 3d printable enclosure that would prevent most of the dirt particles and certain level of moisture from enter in 
    the electronics area, I cannot warranty fully waterproofness.

    However, one of my first backers embedded his board in resin (being careful to leave the reset pushbutton and the USB-C port accessible). 
    He lost access to changing the LiPo, but in addition to a pretty cool design, he gained UV and water resistance.
    
    Regarding sun exposure, the e-paper display degrades under direct UV light exposure. For this, there are some UV blocking films, 
    but at the moment are not mounted on the e-paper displays I sell with the Smart Plant. However they can be acquired on Amazon and 
    placed over the display.

The illluminance sensor doesn't seem to present the right values. 
    Since the VEML7700 gains can be adjusted via software to optimize the illluminance measurement, please have a look at the `Adafruit's tutorial <https://learn.adafruit.com/adafruit-veml7700/adjusting-for-different-light-levels>`_.

What is battery life on single charge?
    With the ESPHome configuration YAML, (10s working and e-paper update, and 1h on deep sleep mode) the expected battery life is around 40-50 days. 
    If you use it without the WiFi settings even more.

Can I attach a solar panel to extend the battery?
    Yes, there are two unsoldered pins marked as +/- where you can attach a 5V solar pannel of your choice. Just make sure the size is fitting 
    the rear cover's size so you can make two holes for passing the wires and glue it carefully to the surface.
    When placing the SmartPlant in the pot, just make sure the sun exposed area is the solar panel and not the e-ink display.

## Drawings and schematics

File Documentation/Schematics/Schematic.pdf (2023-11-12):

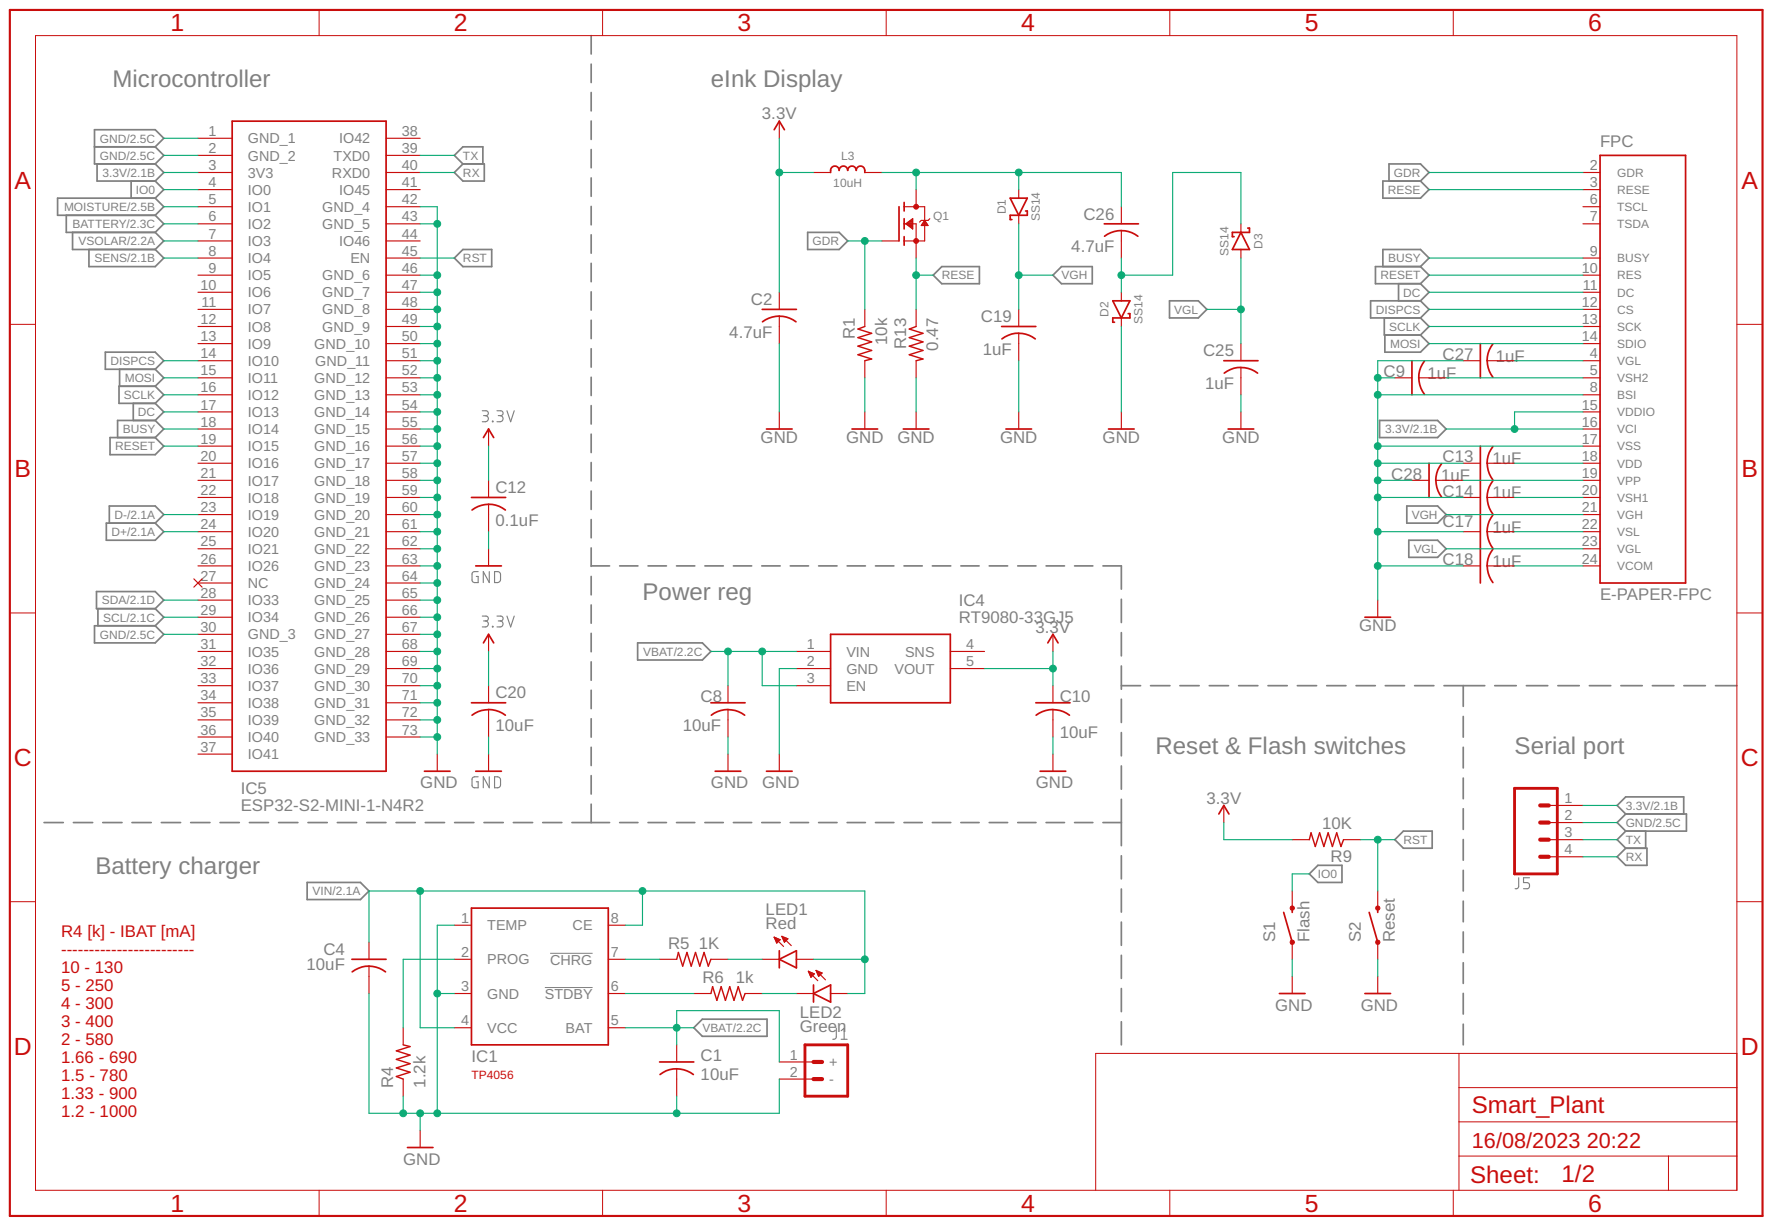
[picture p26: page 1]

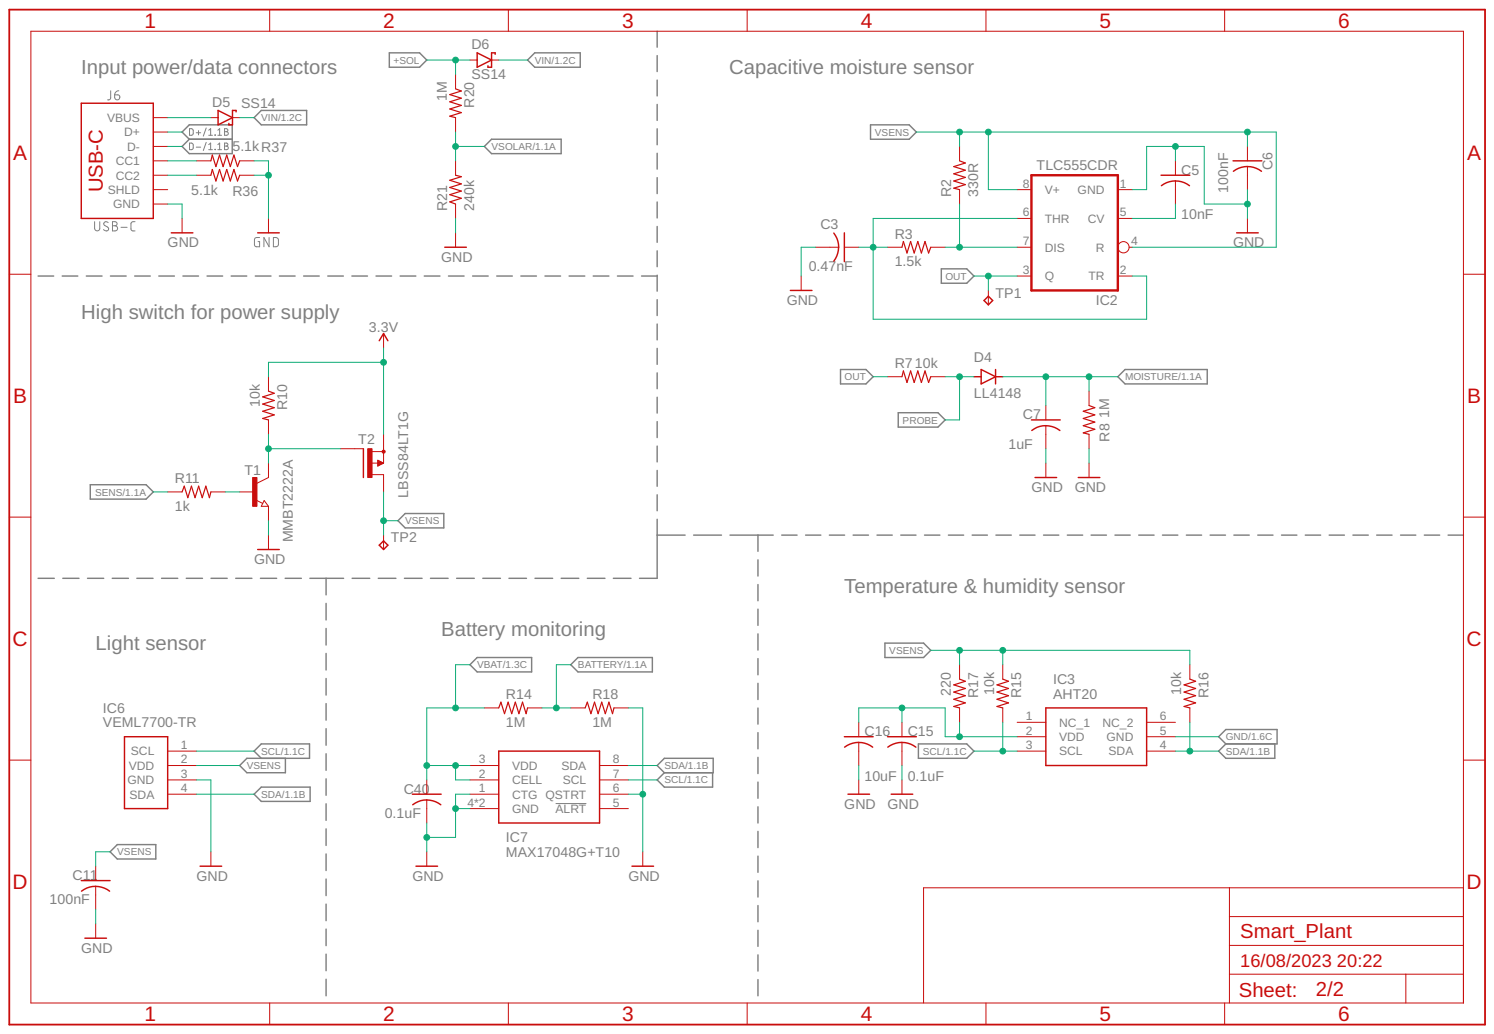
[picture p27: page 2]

Input power/data connectors
VBUS CC1 D+D- CC2 SHLD

High switch for power supply

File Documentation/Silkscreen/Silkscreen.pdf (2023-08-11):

# Smart Plant

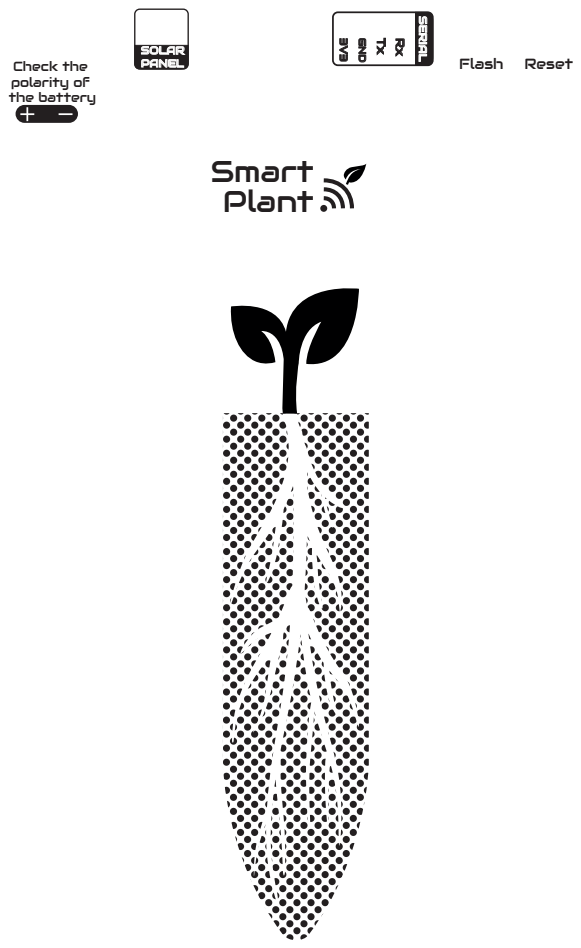
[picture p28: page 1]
Flash Reset; GND; SERIAL; Check the polarity of the battery; SOLAR PANEL

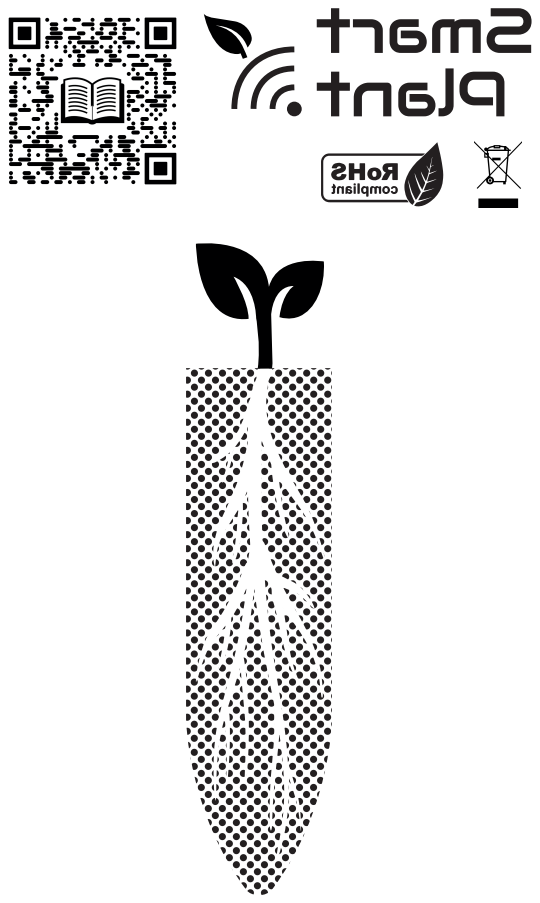
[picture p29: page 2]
Smart Plant

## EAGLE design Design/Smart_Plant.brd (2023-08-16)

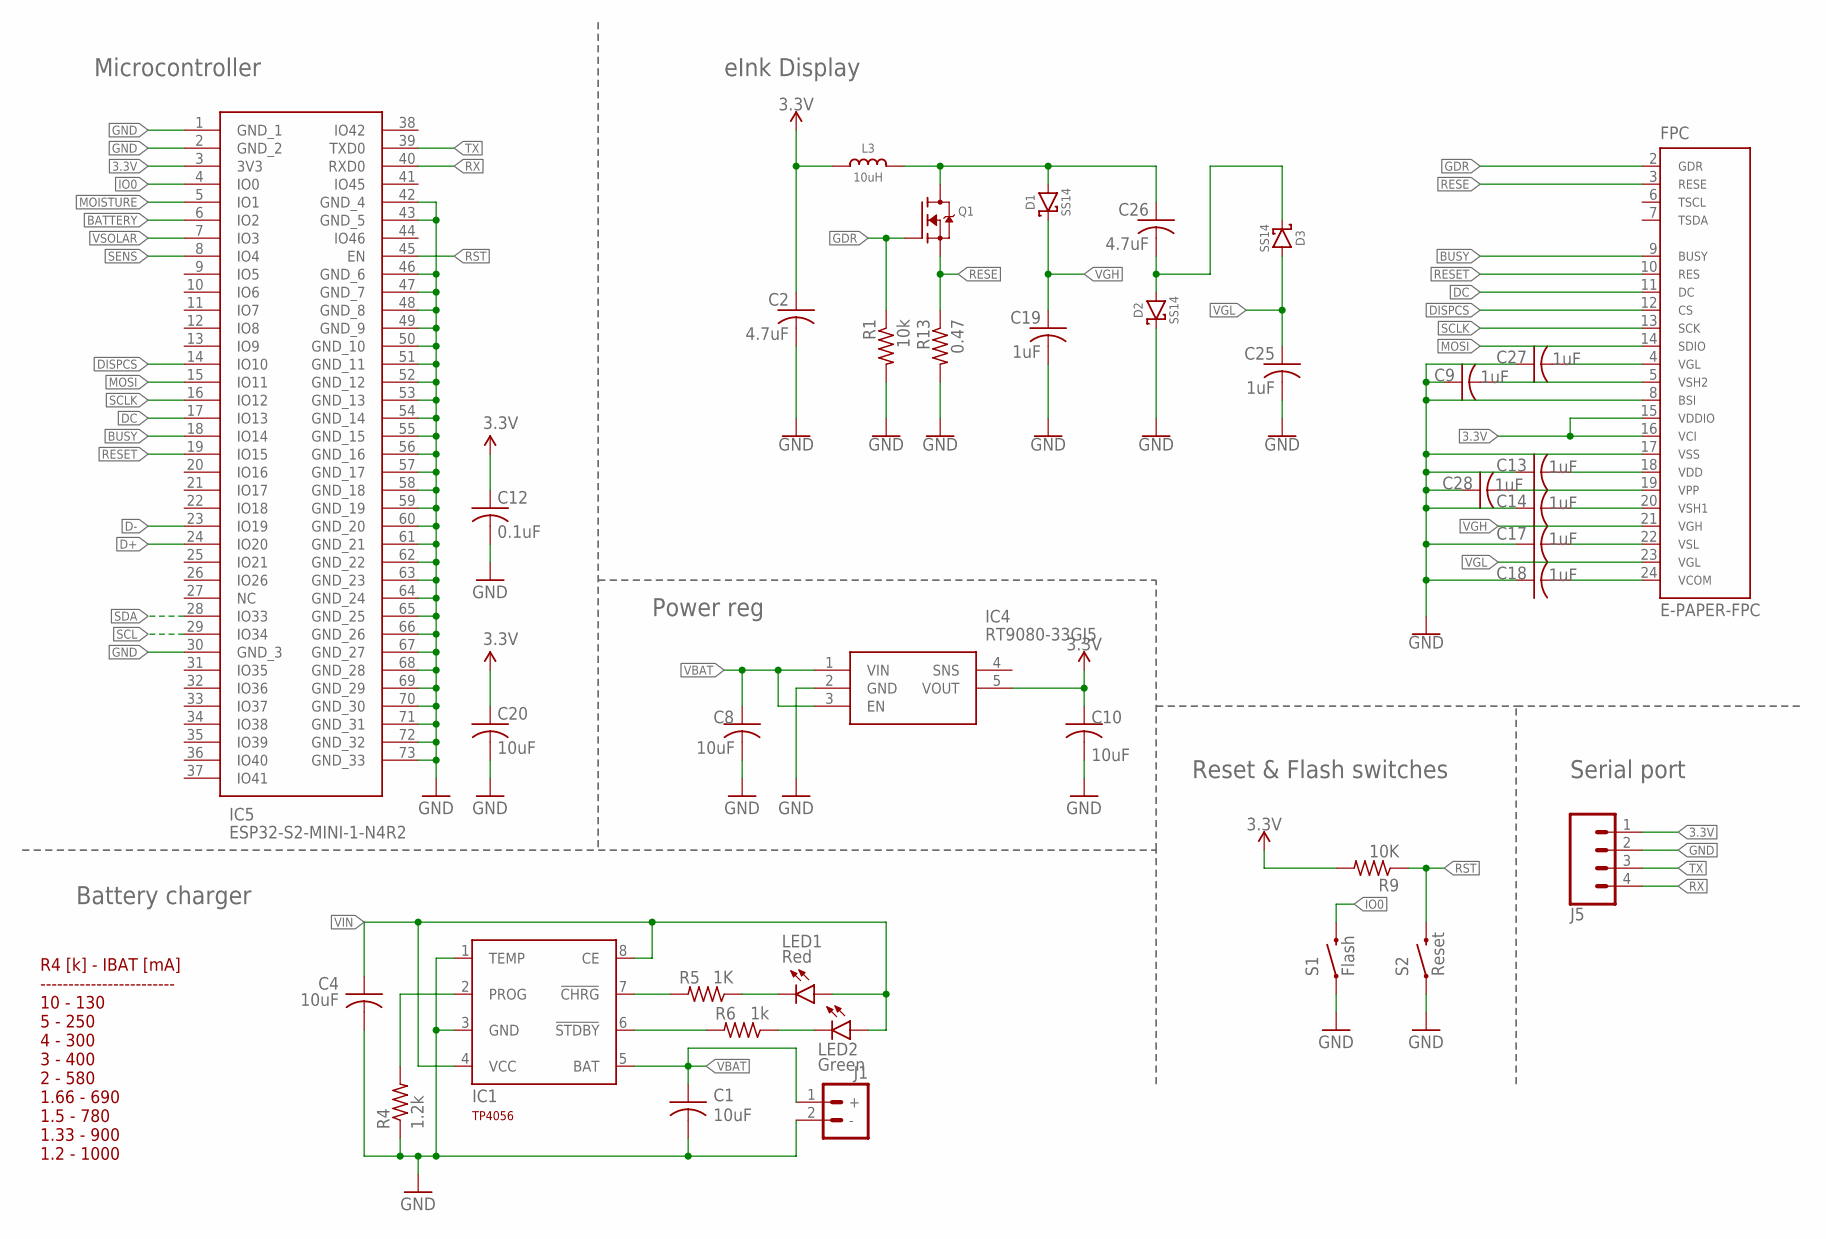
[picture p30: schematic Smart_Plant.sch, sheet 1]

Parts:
C1, C4, C8, C10, C20: 10uF; C0603
C2, C26: 4.7uF; C0603
C9, C13, C14, C17, C18, C19, C25, C27, C28: 1uF; C0603
C12: 0.1uF; C0603
D1, D2, D3: SS14; SMA-DIODE
FPC: E-PAPER-FPC; FPC_24_0.5MM
IC1: TP4056; SOT23-8; LCSC C16581
IC4: RT9080-33GJ5; SOT94P280X100-5N; LCSC C841192
IC5: ESP32-S2-MINI-1-N4R2; ESP32S2MINI1N4R2
J1: BAT_CONN-JST-2MM-SMT; JST-2-SMD
J5: CONN_04PTH; 1X04
L3: 10uH; INDUCTOR_4X4MM_NR401
LED1: Red; LED_0603; LCSC C2286
LED2: Green; LED_0603; LCSC C72043
Q1: IRLML0100; SOT23-3
R1: 10k; R0603
R4: 1.2k; R0603
R5: 1K; R0603
R6: 1k; R0603
R9: 10K; R0603
R13: 0.47; R0603
S1: Flash; TACTILE_SWITCH_SMD_5.2MM
S2: Reset; TACTILE_SWITCH_SMD_5.2MM

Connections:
3.3V: C2.1, C10.1, C12.1, C20.1, FPC.15, FPC.16, IC4.5 (VOUT), IC5.3 (3V3), J5.1, L3.P$2 (2), R9.2; also elsewhere on the board
BATTERY: IC5.6 (IO2); also elsewhere on the board
BUSY: FPC.9, IC5.18 (IO14)
D+: IC5.24 (IO20); also elsewhere on the board
D-: IC5.23 (IO19); also elsewhere on the board
DC: FPC.11, IC5.17 (IO13)
DISPCS: FPC.12, IC5.14 (IO10)
GDR: FPC.2, Q1.1 (G), R1.1
GND: C1.2, C2.2, C4.2, C8.2, C9.1, C10.2, C12.2, C13.1, C14.1, C17.1, C18.1, C19.2, C20.2, C25.2, C27.1, C28.1, D2.C, FPC.8, FPC.17, IC1.1 (TEMP), IC1.3 (GND), IC4.2 (GND), IC5.1 (GND_1), IC5.2 (GND_2), IC5.30 (GND_3), IC5.42 (GND_4), IC5.43 (GND_5), IC5.46 (GND_6), IC5.47 (GND_7), IC5.48 (GND_8), IC5.49 (GND_9), IC5.50 (GND_10), IC5.51 (GND_11), IC5.52 (GND_12), IC5.53 (GND_13), IC5.54 (GND_14), IC5.55 (GND_15), IC5.56 (GND_16), IC5.57 (GND_17), IC5.58 (GND_18), IC5.59 (GND_19), IC5.60 (GND_20), IC5.61 (GND_21), IC5.62 (GND_22), IC5.63 (GND_23), IC5.64 (GND_24), IC5.65 (GND_25), IC5.66 (GND_26), IC5.67 (GND_27), IC5.68 (GND_28), IC5.69 (GND_29), IC5.70 (GND_30), IC5.71 (GND_31), IC5.72 (GND_32), IC5.73 (GND_33), J1.2 (-), J5.2, R1.2, R4.1, R13.2, S1.1, S2.1; also elsewhere on the board
IO0: IC5.4 (IO0), S1.3 (2)
MOISTURE: IC5.5 (IO1); also elsewhere on the board
MOSI: FPC.14, IC5.15 (IO11)
unnamed: IC1.6 (!STDBY), R6.2
unnamed: LED1.C, R5.1
unnamed: LED2.C, R6.1
unnamed: IC1.2 (PROG), R4.2
unnamed: IC1.7 (!CHRG), R5.2
unnamed: C9.2, FPC.5
unnamed: C13.2, FPC.18
unnamed: C14.2, FPC.20
unnamed: C17.2, FPC.22
unnamed: C18.2, FPC.24
unnamed: C26.2, D2.A, D3.C
unnamed: C26.1, D1.A, L3.P$1 (1), Q1.3 (D)
unnamed: C27.2, FPC.4
unnamed: C28.2, FPC.19
RESE: FPC.3, Q1.2 (S), R13.1
RESET: FPC.10, IC5.19 (IO15)
RST: IC5.45 (EN), R9.1, S2.3 (2)
RX: IC5.40 (RXD0), J5.4
SCL: IC5.29 (IO34); also elsewhere on the board
SCLK: FPC.13, IC5.16 (IO12)
SDA: IC5.28 (IO33); also elsewhere on the board
SENS: IC5.8 (IO4); also elsewhere on the board
TX: IC5.39 (TXD0), J5.3
VBAT: C1.1, C8.1, IC1.5 (BAT), IC4.1 (VIN), IC4.3 (EN), J1.1 (+); also elsewhere on the board
VGH: C19.1, D1.C, FPC.21
VGL: C25.1, D3.A, FPC.23
VIN: C4.1, IC1.4 (VCC), IC1.8 (CE), LED1.A, LED2.A; also elsewhere on the board
VSOLAR: IC5.7 (IO3); also elsewhere on the board

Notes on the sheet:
Microcontroller
eInk Display
Serial port
R4 [k] - IBAT [mA] ------------------------ 10 - 130 5 - 250 4 - 300 3 - 400 2 - 580 1.66 - 690 1.5 - 780 1.33 - 900 1.2 - 1000
Battery charger
Power reg
Reset & Flash switches

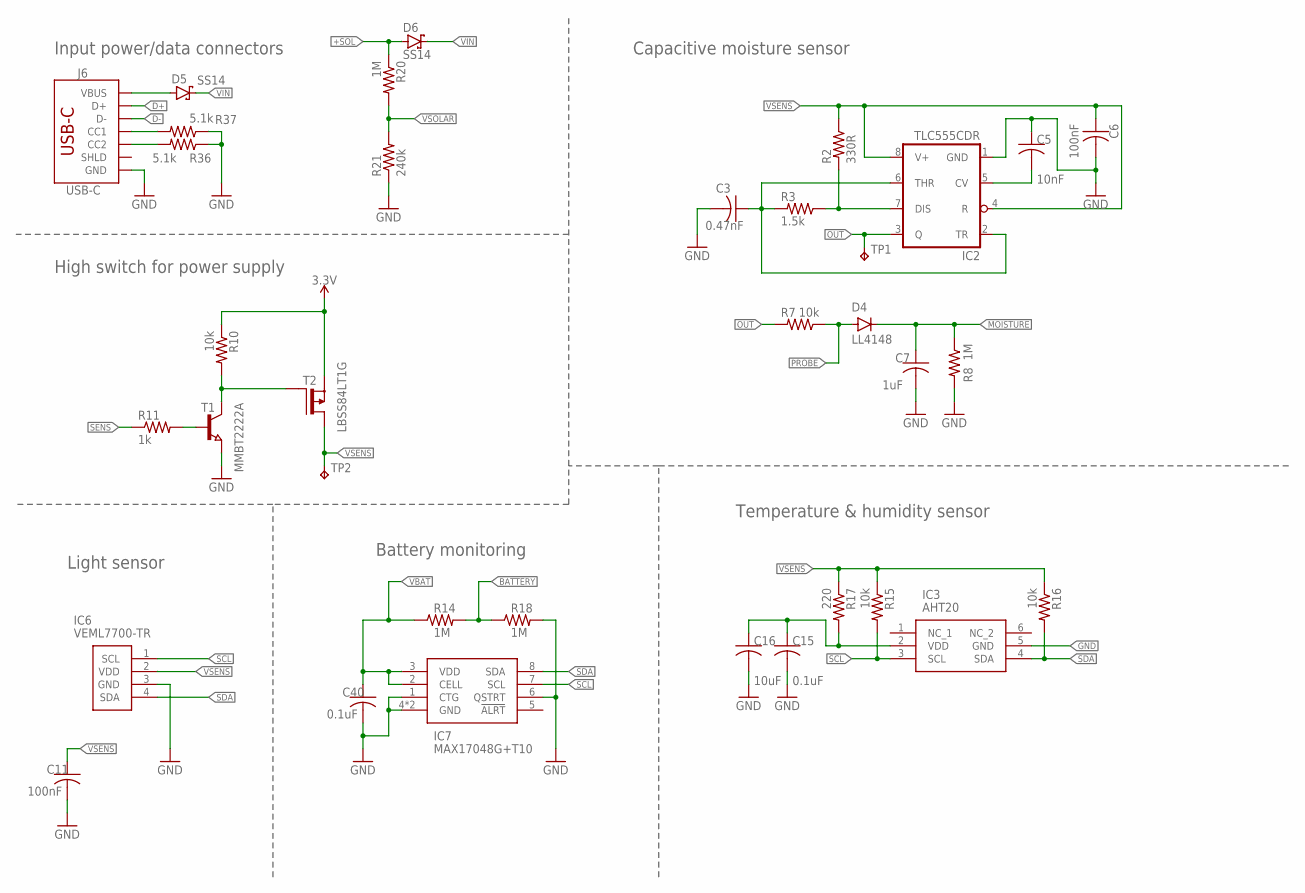
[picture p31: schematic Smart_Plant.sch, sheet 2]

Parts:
C3: 0.47nF; C0603
C5: 10nF; C0603
C6, C11: 100nF; C0603
C7: 1uF; C0603
C15, C40: 0.1uF; C0603
C16: 10uF; C0603
D4: LL4148; LL-34
D5, D6: SS14; SMA-DIODE
IC2: TLC555CDR; SO08
IC3: AHT20
IC6: VEML7700-TR
IC7: MAX17048G+T10; SON50P200X200X80-9N
J6: USB-C; USB-C-16P-4LAYER-ISOLATED; LCSC C2765186
R2: 330R; R0603
R3: 1.5k; R0603
R7, R10, R15, R16: 10k; R0603
R8, R14, R18, R20: 1M; R0603
R11: 1k; R0603
R17: 220; R0603
R21: 240k; R0603
R36, R37: 5.1k; R0603
T1: MMBT2222A; SOT23
T2: LBSS84LT1G; SOT23
TP1, TP2: TPB1,27; B1,27

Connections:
3.3V: R10.1, T2.2 (S); also elsewhere on the board
+SOL: D6.A, R20.1
BATTERY: R14.2, R18.1; also elsewhere on the board
D+: J6.A6 (D+), J6.B6 (D+); also elsewhere on the board
D-: J6.A7 (D-), J6.B7 (D-); also elsewhere on the board
GND: C3.2, C5.1, C6.2, C7.2, C11.2, C15.2, C16.2, C40.2, IC2.1 (GND), IC3.5 (GND), IC6.3 (GND), IC7.1 (CTG), IC7.4 (GND), IC7.6 (QSTRT), IC7.9 (GND), J6.GND, J6.GND2 (GND), R8.2, R18.2, R21.1, R36.1, R37.1, T1.2 (E); also elsewhere on the board
MOISTURE: C7.1, D4.C, R8.1; also elsewhere on the board
unnamed: C3.1, IC2.2 (TR), IC2.6 (THR), R3.2
unnamed: IC2.7 (DIS), R2.2, R3.1
unnamed: C5.2, IC2.5 (CV)
unnamed: R10.2, T1.3 (C), T2.1 (G)
unnamed: C15.1, C16.1, IC3.2 (VDD), R17.2
unnamed: R11.2, T1.1 (B)
unnamed: J6.B5 (CC2), R36.2
unnamed: J6.A5 (CC1), R37.2
OUT: IC2.3 (Q), R7.2, TP1.TP
PROBE: D4.A, R7.1
SCL: IC3.3 (SCL), IC6.1 (SCL), IC7.7 (SCL), R15.2; also elsewhere on the board
SDA: IC3.4 (SDA), IC6.4 (SDA), IC7.8 (SDA), R16.2; also elsewhere on the board
SENS: R11.1; also elsewhere on the board
VBAT: C40.1, IC7.2 (CELL), IC7.3 (VDD), R14.1; also elsewhere on the board
VIN: D5.C, D6.C; also elsewhere on the board
VSENS: C6.1, C11.1, IC2.4 (R), IC2.8 (V+), IC6.2 (VDD), R2.1, R15.1, R16.1, R17.1, T2.3 (D), TP2.TP
VSOLAR: R20.2, R21.2; also elsewhere on the board
V_USB: D5.A, J6.VBUS1 (VBUS), J6.VBUS2 (VBUS)

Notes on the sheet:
Capacitive moisture sensor
High switch for power supply
Light sensor
Temperature & humidity sensor
Battery monitoring
Input power/data connectors

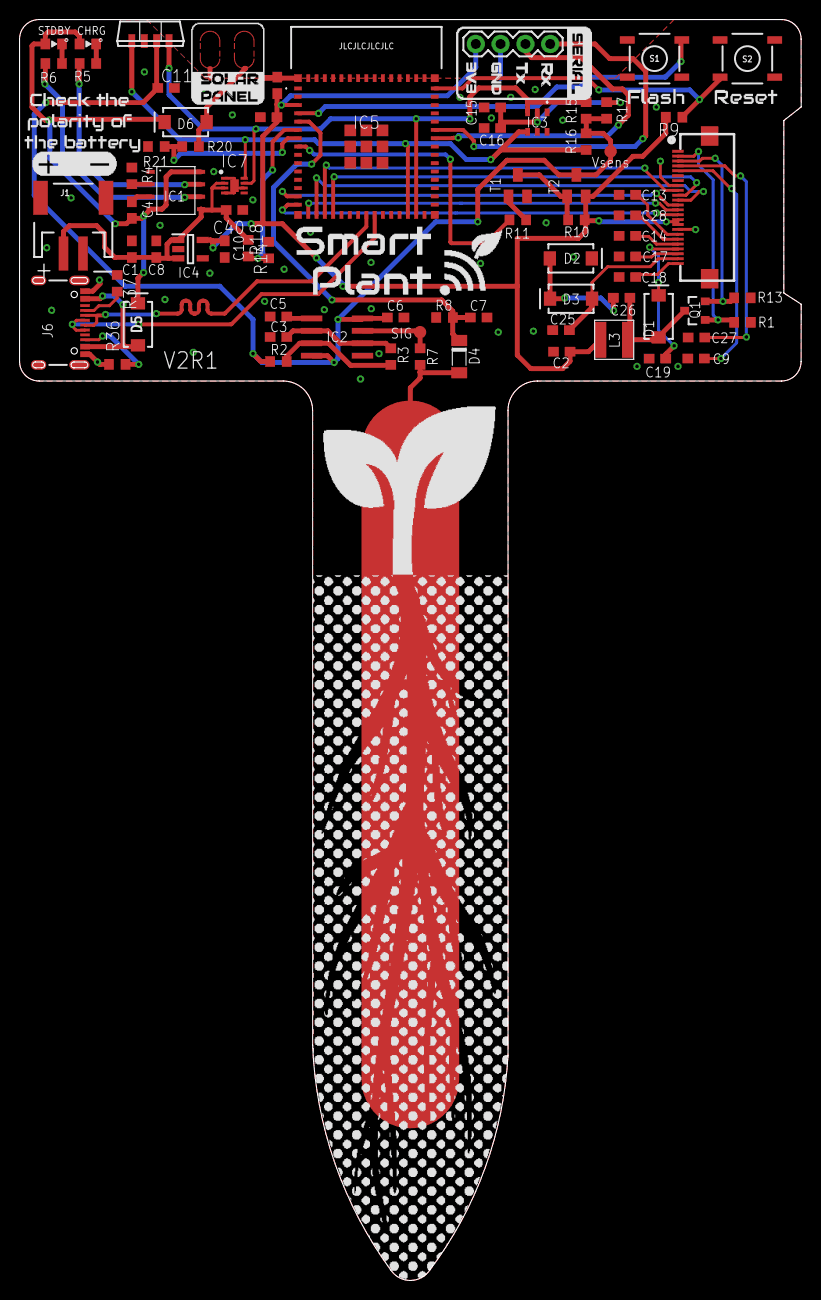
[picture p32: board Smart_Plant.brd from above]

Board: 2 copper layers, 80.0 x 129.1 mm, 73 parts (0 on the bottom side), 53 nets.

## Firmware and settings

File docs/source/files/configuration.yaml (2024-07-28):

substitutions:
  device_name: "smart-plant"
  friendly_name: "Smart Plant"
  project_name: "smart.plant"
  project_version: "2.2"
  ap_pwd: "smartplant"

esphome:
  name: "${device_name}"
  name_add_mac_suffix: true
  project:
    name: "${project_name}"
    version: "${project_version}"
  # Initialize the IIC bus immediatelly after the powering the sensors
  on_boot:
    priority: 600
    then:
     - lambda: |-
        Wire.begin();
        delay(100);

     - script.execute: consider_deep_sleep


esp32:
  board: esp32-s2-saola-1
  framework:
    type: arduino

# Enable logging
logger:

# Enable Home Assistant API
api:

# Enable Over The Air updates
ota:
  - platform: esphome
  
#Public location of this yaml file
dashboard_import:
  package_import_url: github://JGAguado/Smart_Plant/docs/source/files/configuration.yaml@V2R1
  import_full_config: false

# Enable fallback hotspot (captive portal) in case wifi connection fails
captive_portal:

improv_serial:

wifi:
  ap:
    password: "${ap_pwd}"


i2c:
  scl: GPIO34
  sda: GPIO33
  scan: false
  id: bus_a

spi:
  clk_pin:  GPIO12
  mosi_pin: GPIO11
    
image:
  - file: "https://smart-plant.readthedocs.io/en/v2r1/_images/Lemon_tree_label_page_1.png"
    id: page_1_background

font:
  - file: "gfonts://Audiowide"
    id: font_title
    size: 20
  - file: "gfonts://Audiowide"
    id: font_subtitle
    size: 15
  - file: "gfonts://Audiowide"
    id: font_parameters
    size: 15
  - file: 'gfonts://Material+Symbols+Outlined'
    id: font_icon
    size: 20
    glyphs:
      - "\U0000ebdc" # battery empty
      - "\U0000ebd9" # battery 1 bar
      - "\U0000ebe0" # battery 2 bar
      - "\U0000ebdd" # battery 3 bar
      - "\U0000ebe2" # battery 4 bar
      - "\U0000ebd4" # battery 5 bar
      - "\U0000e1a4" # battery full
      - "\U0000e627" # sync

time:
  - platform: homeassistant
    id: esptime

switch:
  - platform: gpio
    pin: GPIO4
    id: exc
    name: "Excitation switch"
    icon: "mdi:power"
    restore_mode: ALWAYS_ON  
    
    
sensor:    

  # Battery level sensor    
  - platform: adc
    name: "Battery Voltage"
    id: batvolt
    pin: GPIO2
    accuracy_decimals: 2
    update_interval: 1s
    unit_of_measurement: "V"
    attenuation: 12db
    icon: mdi:battery-medium
    filters:
      - multiply: 2.15
      - median:
          window_size: 7
          send_every: 7
          send_first_at: 7
    on_value:
      then:
        - component.update: batpercent

  - platform: template
    name: "Battery %"
    id: batpercent
    lambda: return id(batvolt).state;
    accuracy_decimals: 0
    unit_of_measurement: "%"
    icon: mdi:battery-medium
    filters:
      - calibrate_linear:
         method: exact
         datapoints:
          - 0.00 -> 0.0
          - 3.30 -> 1.0
          - 3.39 -> 10.0
          - 3.75 -> 50.0
          - 4.11 -> 90.0
          - 4.20 -> 100.0
      - lambda: |-
          if (x <= 100) {
            return x;
          } else {
            return 100;
          }
          if (x <0) {
            return 0;
          }

  # Temperature and humidity sensor
  - platform: aht10
    variant: AHT20 
    i2c_id: bus_a
    temperature:
      name: "Temperature"
      id: temp
      icon: "mdi:thermometer"
    humidity:
      name: "Air Humidity"
      id: hum
      icon: "mdi:water-percent"
    update_interval: 3s

  # Light sensor
  - platform: veml7700
    address: 0x10
    update_interval: 1s
    ambient_light: 
      name: "Ambient light"
      id: light
      icon: "mdi:white-balance-sunny"
    actual_gain:
      name: "Actual gain"
        
  # Capacitive soil moisture sensor
  - platform: adc
    pin: GPIO1
    name: "Soil Moisture"
    id : soil
    icon: "mdi:cup-water"
    update_interval: 1s
    unit_of_measurement: "%"
    attenuation: 12db
    filters:
    - median:
        window_size: 5
        send_every: 5

    - calibrate_linear:
        - 1.25 -> 100.00
        - 2.8 -> 0.00
    - lambda: if (x < 1) return 0; else if (x > 100) return 100; return (x);
    accuracy_decimals: 0
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

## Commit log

2022-10-02 Updated design files for Smart_Plant
    [Smart_Plant.brd, Smart_Plant.sch]
2022-10-02 Added silkscreen files
2022-10-06 Update design files
    [Smart_Plant.brd, Smart_Plant.sch]
2022-10-06 updated Silkscreen
2022-10-22 Resistors charger note
    [Smart_Plant.sch]
2023-02-12 Added power patch
    [Smart_Plant.brd, Smart_Plant.sch]
2023-02-12 Added schematics to documentation
2023-02-12 Added enclosure 3d files
    [Printable Smart-Plant.stp, Smart Plant Enclosure Solar Top.stl, Smart Plant Enclosure Solar.stl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]
2023-03-11 Released designs from V1R1 with the patch board
    [Smart_Plant.brd, Smart_Plant_patch.brd, Smart_Plant_patch.sch]
2023-04-02 Added designs for V1R2
    [Smart_Plant.brd, Smart_Plant.sch, Smart_Plant_patch.brd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]
2023-04-02 Added enclosure files for V1R2
    [Printable Smart-Plant.stp, Smart-Plant Enclosure Bottom.stl, Smart-Plant Enclosure Top.stl]
2023-04-02 Updated schematics
2023-06-27 SoC first draft
    [Smart_Plant.brd, Smart_Plant.sch]
2023-07-02 Updated enclosure files
    [Printable Smart-Plant.stp, Smart Plant Enclosure Solar Top.stl, Smart Plant Enclosure Solar.stl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]
2023-08-11 Design V1R3
    [Smart_Plant.brd, Smart_Plant.sch]
2023-08-11 Silkscreen V1R3
2023-08-16 First draft of the V2R1 design
    [Smart_Plant.brd, Smart_Plant.sch]
2023-11-12 Added enclosures
    [Smart-Plant Enclosure Bottom.stl, Smart-Plant Enclosure Top.stl]
2023-11-12 Enclosures update
    [Smart-Plant Enclosure Bottom.stl, Smart-Plant Enclosure ButtonPin.stl, Smart-Plant Enclosure Top.stl]
2023-12-29 Restructured Enclosure folder with updated files
    [Smart-Plant Enclosure Bottom.stl, Smart-Plant Enclosure Top - Transparent.stl, Smart-Plant Enclosure Top.stl]
2024-01-30 Added STP files
    [Smart-Plant Enclosure Bottom.stp, Smart-Plant Enclosure Top - Transparent.stp, Smart-Plant Enclosure Top.stp]
2024-01-31 Update configuration.yaml
    issue was lux -> lx in order to have it work in homeassistant
    [configuration.yaml]

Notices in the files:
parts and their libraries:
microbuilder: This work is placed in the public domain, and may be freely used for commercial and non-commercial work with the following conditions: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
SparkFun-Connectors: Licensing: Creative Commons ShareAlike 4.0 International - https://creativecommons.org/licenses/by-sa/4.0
